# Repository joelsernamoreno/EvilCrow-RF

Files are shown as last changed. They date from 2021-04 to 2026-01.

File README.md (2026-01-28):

# EvilCrow-RF

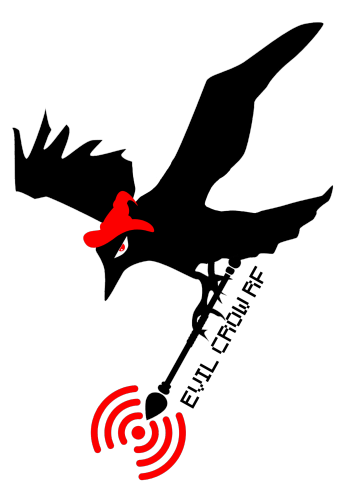
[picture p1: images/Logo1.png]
EvilCrow


**Idea, development and implementation:** Joel Serna (@JoelSernaMoreno).

**PCB design:** Ignacio Díaz Álvarez (@Nacon_96) and Forensic Security (@ForensicSec).

**Manufacturer and distributor:** April Brother (@aprbrother).

**Distributor from United Kingdom:** KSEC Worldwide (@KSEC_KC).

**Collaborators:** Little Satan, Ernesto Sánchez (@ernesto_xload), Federico Maggi (@phretor), Andrea Guglielmini (@Guglio95) and RFQuack (@rfquack).

The developers and collaborators of this project do not earn money with this. 
You can invite me for a coffee to further develop Low-Cost hacking devices. If you don't invite me for a coffee, nothing happens, I will continue developing devices.



**For sale with April Brother (shipping from China):** 

* [Aliexpress Shop](https://aliexpress.com/item/1005002476481892.html)

**For sale with KSEC Worldwide (shipping from United Kingdom):**

* Evil Crow RF: https://labs.ksec.co.uk/product/evil-crow-rf/

**Discord Group:** https://discord.gg/jECPUtdrnW

**Summary:**

1. Disclaimer
2. Introduction
3. Firmware
	* Installation
	* First steps with Evil Crow RF
	* Home
	* RX Config
	* Log Viewer
	* TX Config
	* Config
4. Advanced Firmware with RFQuack
	* Installation and first steps
	* RX Example
	* TX Example
	* Public Demo
5. Evil Crow RF Support

# Disclaimer

Evil Crow RF is a basic device for professionals and cybersecurity enthusiasts.

We are not responsible for the incorrect use of Evil Crow RF.

We recommend using this device for testing, learning and fun :D

**Be careful with this device and the transmission of signals. Make sure to follow the laws that apply to your country.**

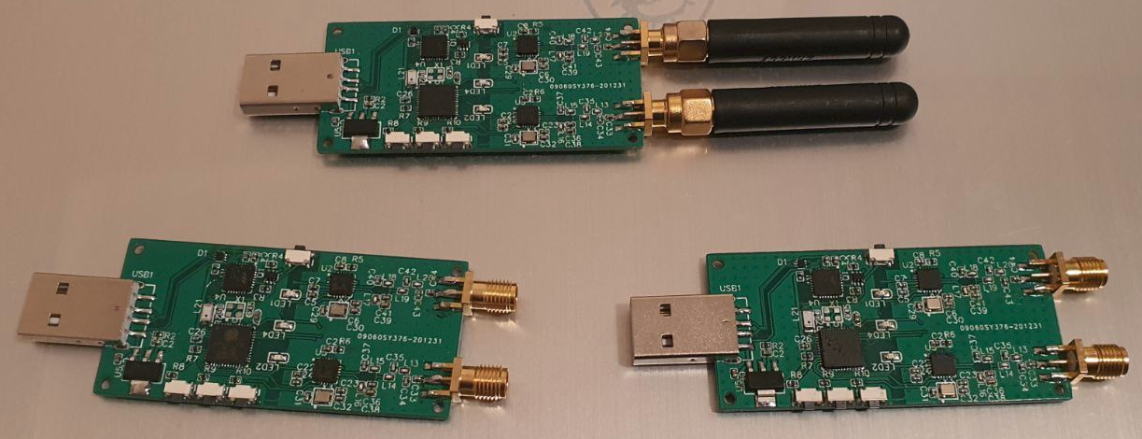
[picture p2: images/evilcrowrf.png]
EvilCrowRF


# Introduction

Evil Crow RF is a radiofrequency hacking device for pentest and Red Team operations, this device operates in the following radiofrequency bands:

* 300Mhz-348Mhz
* 387Mhz-464Mhz
* 779Mhz-928Mhz

Evil Crow RF has two CC1101 radiofrequency modules, these modules can be configured to transmit or receive on different frequencies at the same time.

Evil Crow RF allows the following attacks:

* Signal receiver
* Signal transmitter
* Replay attack
* Brute Force
* ...

**NOTE:** 

* All devices have been flashed with basic firmware EvilCrow-RF before shipping.
* Please do not ask me to implement new functions in this code. You can develop code for Evil Crow RF and send PR with your new code.

# Firmware

The basic firmware allows to receive and transmit signals. You can configure the two radio modules through a web panel via WiFi.

## Installation

1. Install esptool: sudo apt install esptool
2. Install pyserial: sudo pip install pyserial
3. Download and install the latest version of Arduino IDE (v2.3.6): https://www.arduino.cc/en/main/software
4. Download EvilCrow-RF repository: git clone https://github.com/joelsernamoreno/EvilCrow-RF.git
5. Download the ESPAsyncWebServer library in the Arduino library directory: git clone https://github.com/ESP32Async/ESPAsyncWebServer.git
6. Download the ElegantOTA library in the Arduino library directory: git clone https://github.com/ayushsharma82/ElegantOTA.git
7. Edit ElegantOTA/src/ElegantOTA.h and chage the following:

* #define ELEGANTOTA_USE_ASYNC_WEBSERVER 0 to #define ELEGANTOTA_USE_ASYNC_WEBSERVER 1

8. Download the AsyncTCP library in the Arduino library directory: git clone https://github.com/ESP32Async/AsyncTCP.git
9. Open Arduino IDE
10. Go to File - Preferences. Locate the field "Additional Board Manager URLs:" Add "https://espressif.github.io/arduino-esp32/package_esp32_index.json" without quotes. Click "Ok"
11. Select Tools - Board - Boards Manager. Search for "esp32". Install "esp32 by Espressif system version 3.3.2". Click "Close".
12. Open the EvilCrow-RF/firmware/firmware/firmware.ino sketch
13. Select Tools:
    * Board - "ESP32 Dev Module".
    * Flash Size - "4MB (32Mb)".
    * CPU Frequency - "80MHz (WiFi/BT)".
    * Flash Frequency - "40MHz"
    * Flash Mode - "DIO"
14. Upload the code to the Evil Crow RF device
15. Press reset button

## First steps with Evil Crow RF

1. Set up a Wi-Fi AP with your mobile phone:
	* **SSID:** Evil Crow RF
	* **Password:** 123456789ECRFv1
2. Connect your laptop to the same Wi-Fi network.
3. Open a browser and access the web panel: http://evilcrow-rf.local/

**Note:** If you cannot access the web panel, use the IP address assigned to Evil Crow RF or follow below steps **only if you are running Linux OS:**
 * check if avahi-deamon is installed and running on your PC. You can do this with executing "sudo systemctl status avahi-daemon" in terminal
 * If service is not running, install it using your package manager (apt, yum, dnf, Packman, rpm,...)
 * After successful installation, start avahi-daemon service with "sudo systemctl start avahi-daemon && sudo systemctl enable avahi-daemon"
 * In case evilcrow-rf.local is still not reachable, use http://"IP address", where "IP address" is IP assigned to Evil Crow RF.
 
## Home

The Home page shows interesting information about the device.

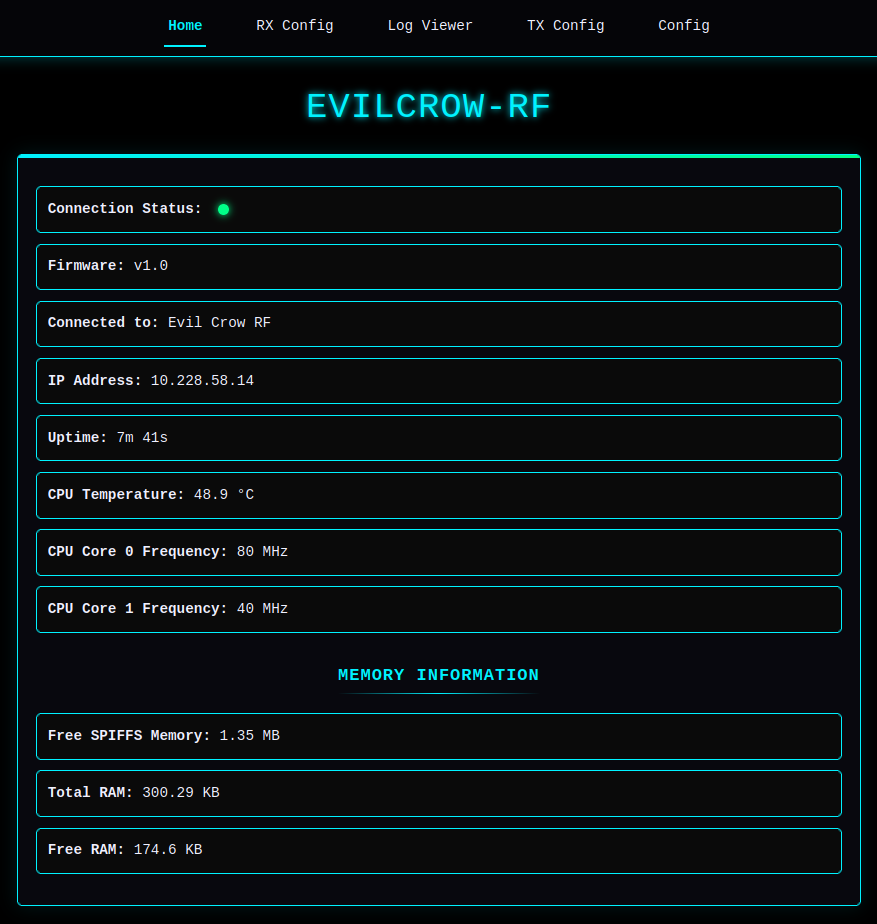
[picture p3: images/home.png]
Home


## RX Config

The RX Config page allows you to configure the CC101 modules for receiving signals. The received signals are displayed in the Log Viewer.

* Module: (1 for first CC1101 module, 2 for second CC1101 module)
* Modulation: (example ASK/OOK)
* Frequency: (example 433.92)
* Rx bandwidth: (example 200)
* Deviation: (example 0)
* Data rate: (example 5)

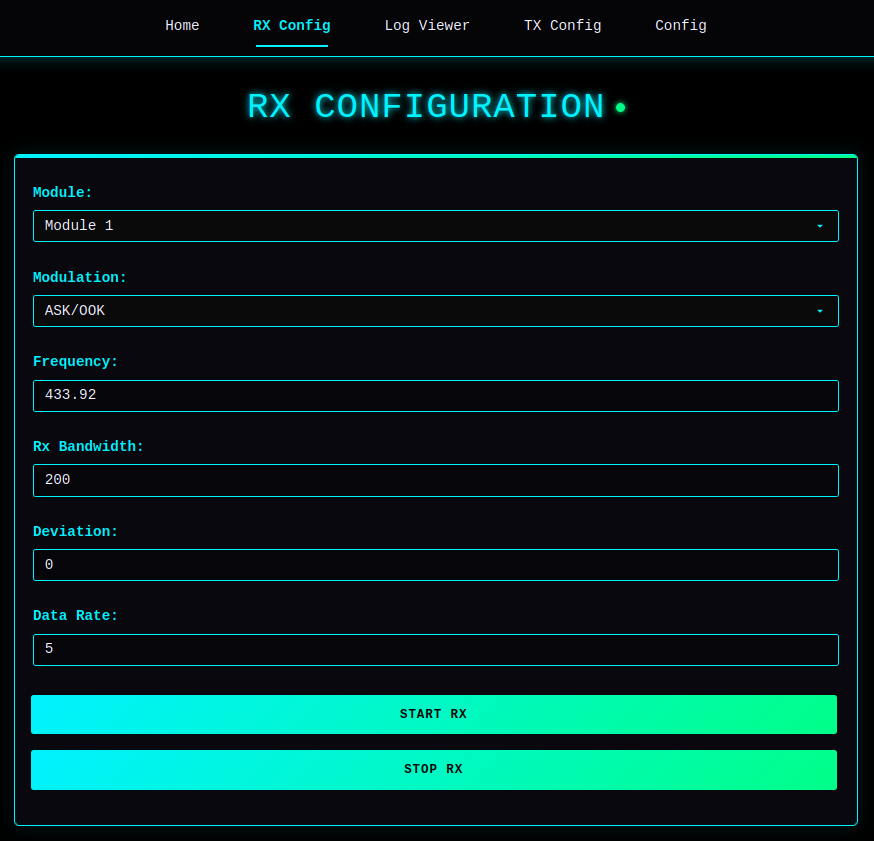
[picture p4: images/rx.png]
RX


## Log Viewer

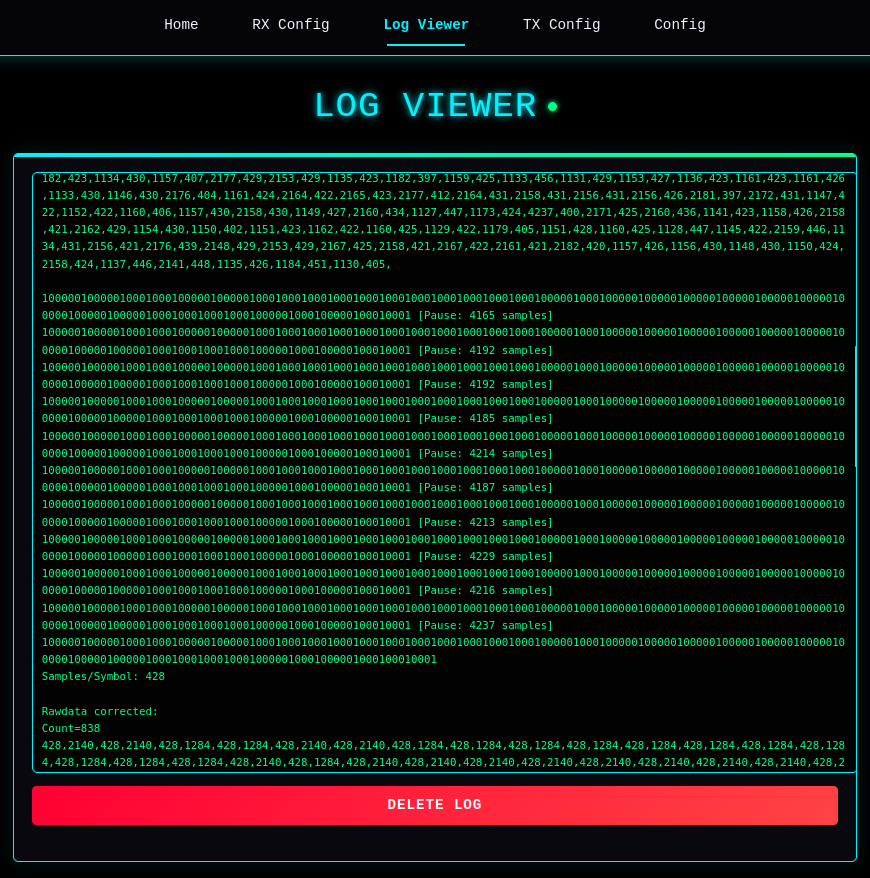
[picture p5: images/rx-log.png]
RXLog


## TX Config

The TX Config page allows you to transmit a raw data signal or enable/disable the jammer.

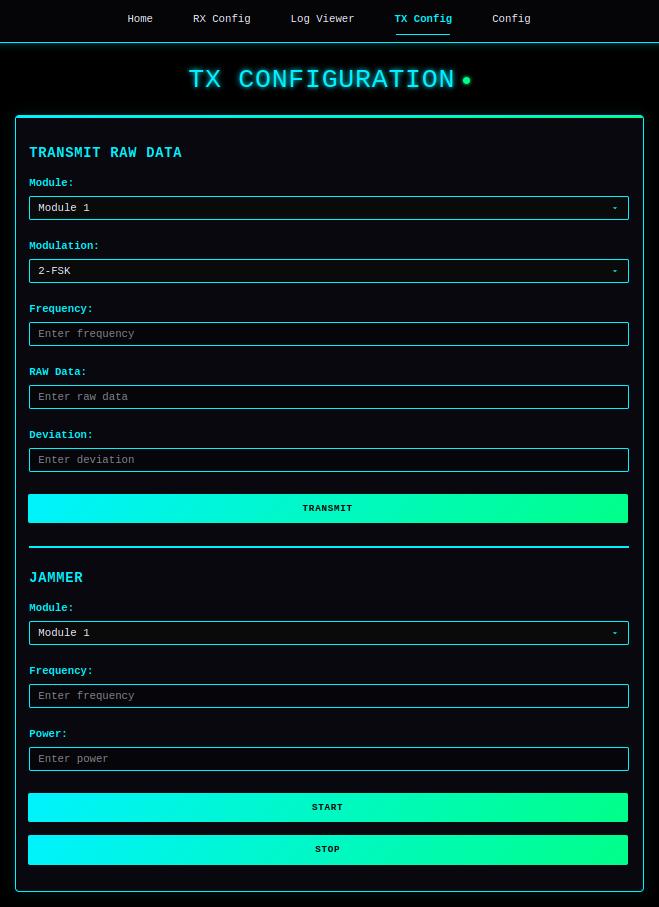
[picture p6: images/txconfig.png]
TXCONFIG


* **TX Raw Data:**

* Module: (1 for first CC1101 module, 2 for second CC1101 module)
* Modulation: (example ASK/OOK)
* Frequency: (example 433.92)
* RAW Data: (raw data or raw data corrected displayed in Log Viewer)
* Deviation: (example 0)

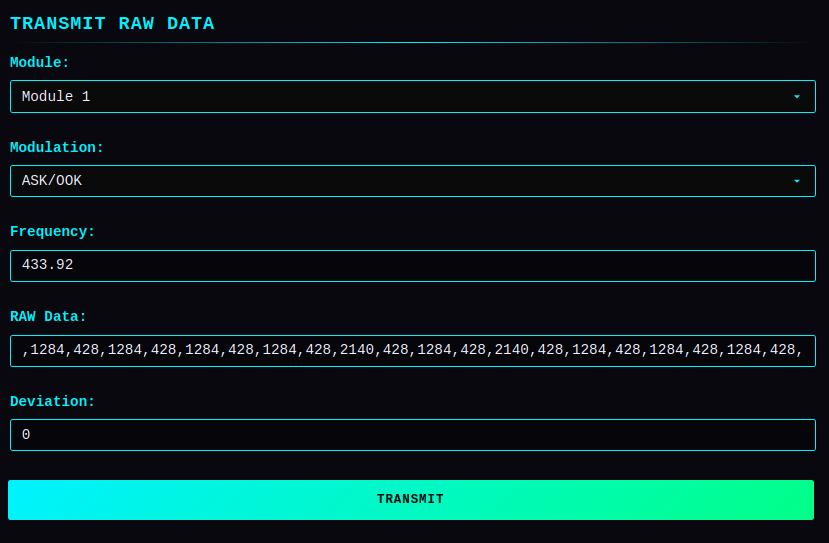
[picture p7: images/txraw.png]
TXRAW


* **Jammer:**

* Module: (1 for first CC1101 module, 2 for second CC1101 module)
* Frequency: (example: 433.92)
* Jammer Power: (example: 12)

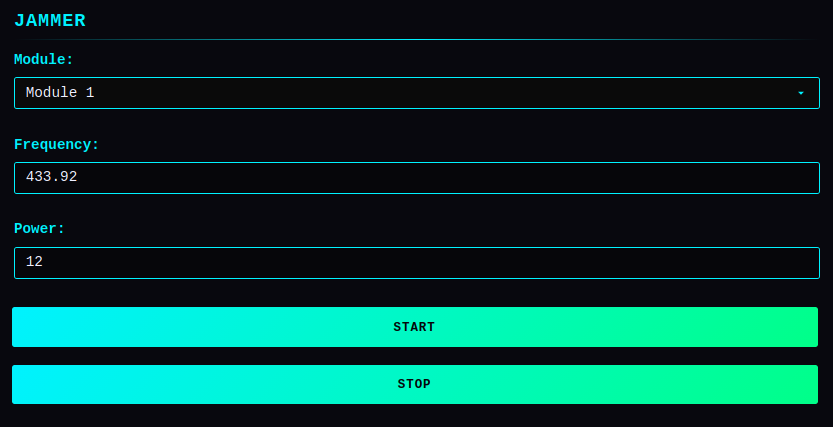
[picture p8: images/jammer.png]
JAMMER


## Config

The Config page allows you to change the Wi-Fi configuration.

**NOTE:** Evil Crow RF is configured in STATION MODE. You can change the ssid and password from the web panel.

The changes will be stored in the device, every time you restart Evil Crow RF the new Wi-Fi settings will be applied. If you want to return to the default settings, you can delete the stored Wi-Fi configuration from the web panel.

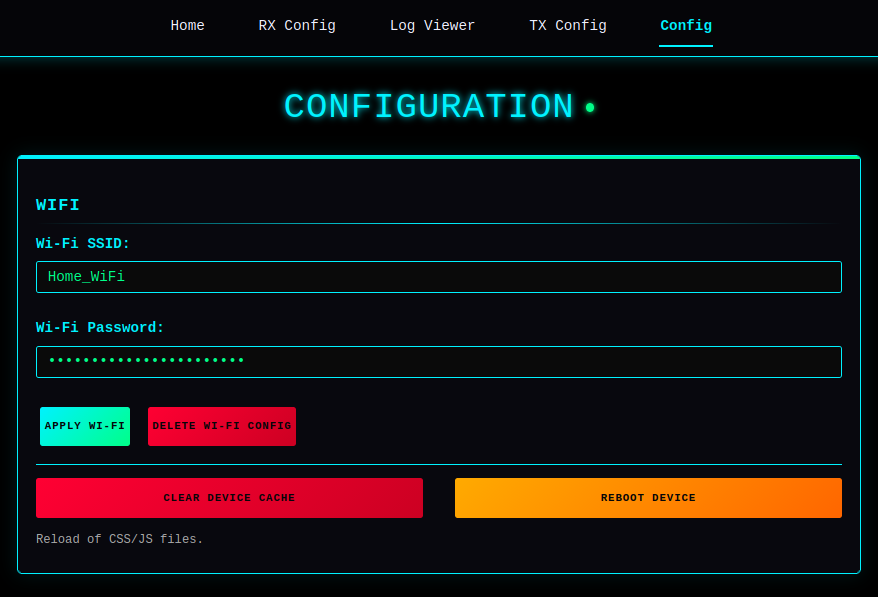
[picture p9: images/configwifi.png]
CONFIG


# Advanced Firmware with RFQuack

RFQuack is the only versatile RF-analysis tool that quacks!

It's a library firmware that allows you to sniff, manipulate, and transmit data over the air. Consider it as the hardware-agnostic and developer-friendly version of the great YardStick One, which is based on the CC1101 radio chip. Similarly to RFCat, RFQuack has a console-based, Python-scriptable client that allows you to set parameters, receive, transmit, and so on.

RFQuack is compatible with Evil Crow RF :D

## Installation and first steps

1. Download the RFQuack repository: git clone https://github.com/rfquack/RFQuack.git

2. Go to RFQuack directory: cd RFQuack

3. Edit build.env with this content:

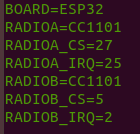
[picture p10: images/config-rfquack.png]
Content


4. Execute the following command: make docker-build-nc && make build

5. Connect Evil Crow RF to your computer and flash RFQuack with the following command: PORT=/dev/ttyUSB0 make flash

6. Disconnect and connect Evil Crow RF again

7. Download the RFQuack-cli repository: git clone https://github.com/rfquack/RFQuack-cli.git

8. Go to RFQuack-cli directory: cd RFQuack-cli

9. Execute the following command: make docker-build

10. Execute the following command: docker run --device /dev/ttyUSB0 --rm -it rfquack/cli:latest tty -P /dev/ttyUSB0

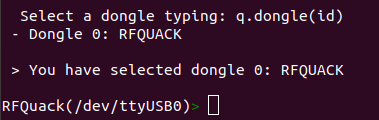
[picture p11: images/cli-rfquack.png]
Cli


## RX Example

In the RFQuack console run the following commands:

1. q.radioA.set_modem_config(modulation="OOK", carrierFreq=433.920, syncWords=b"", useCRC=False, bitRate=1.7*2, rxBandwidth=58)
2. q.radioA.set_packet_len(isFixedPacketLen=True, packetLen=100)
3. q.radioA.rx()

This is a simple example, read the documentation for information: https://github.com/rfquack/RFQuack

## TX Example

This example performs a replay attack with the signal received in the RX example.
In the RFQuack console run the following commands:

1. len(q.data)
2. q.radioA.tx()
3. q.radioA.send(data=q.data[0].data)

This is a simple example, read the documentation for information: https://github.com/rfquack/RFQuack

## Public Demo

* RX example: https://twitter.com/JoelSernaMoreno/status/1354854848299208706

# Evil Crow RF Support

* You can ask in the Discord group: https://discord.gg/jECPUtdrnW
* You can open issue or send me a message via twitter (@JoelSernaMoreno).

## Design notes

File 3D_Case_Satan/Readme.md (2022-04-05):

# Screwless housing for Evil Crow Rf v.1

"OldStyle"
The STL files do not contain support structures for 3D printing
You have to find out for yourself how it is best printed. 
I printed it with an SLA printer and had to print the housing parts upright for best printing results.

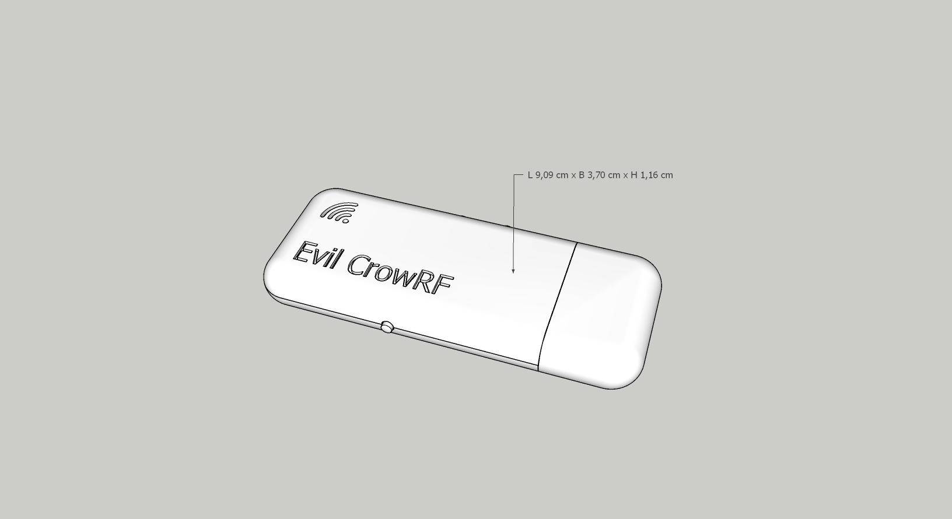
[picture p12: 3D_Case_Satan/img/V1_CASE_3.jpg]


"NewStyle"
Redesigned V1 case for better printability with the same size.(length including cap)

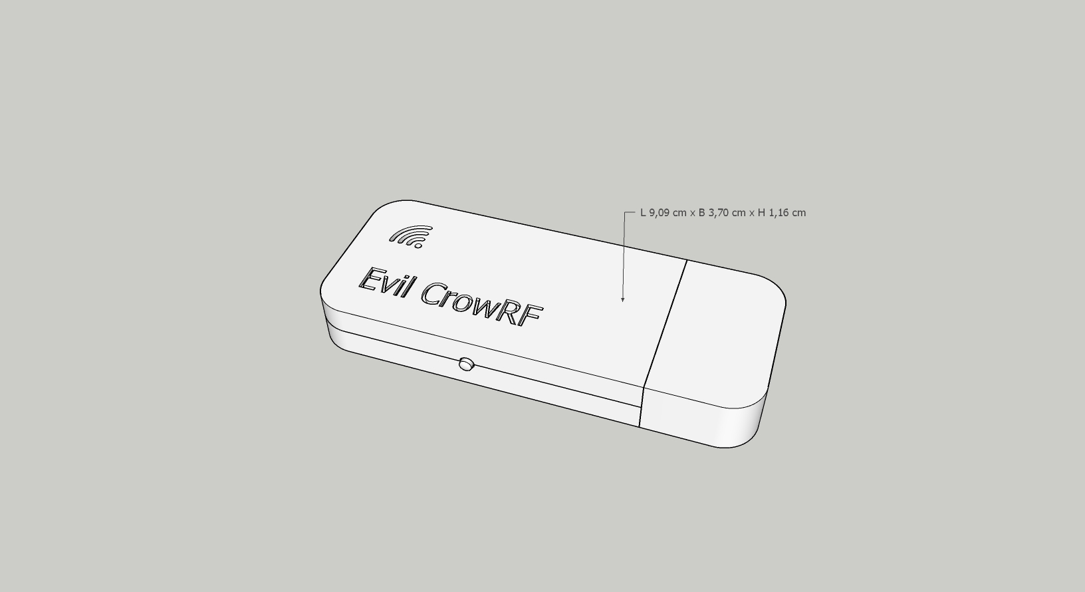
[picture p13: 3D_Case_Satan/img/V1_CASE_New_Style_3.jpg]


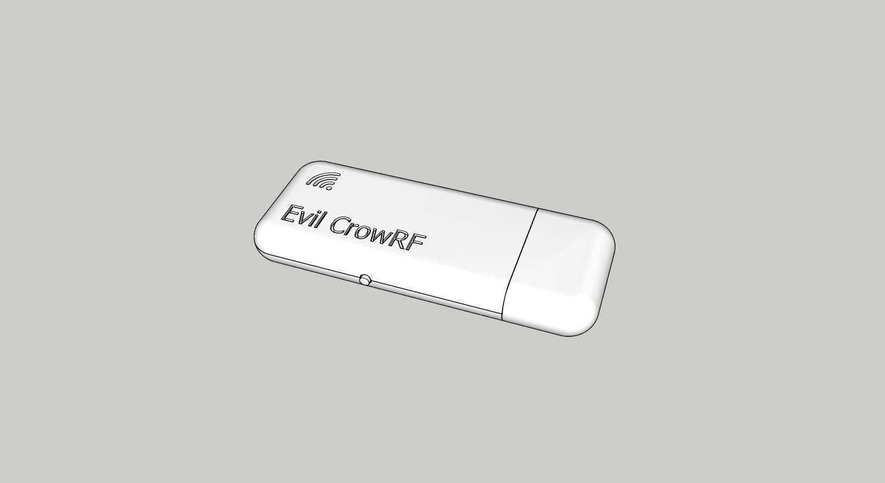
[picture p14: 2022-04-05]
3D_Case_Satan/img/V1_CASE_1.jpg

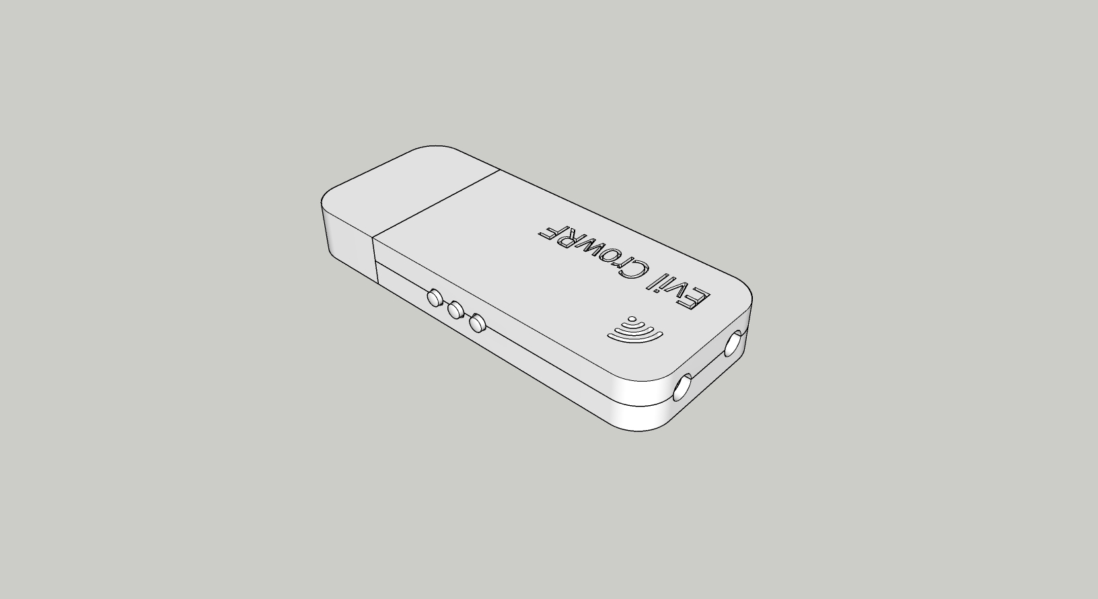
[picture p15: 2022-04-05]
3D_Case_Satan/img/V1_CASE_New_Style_2.jpg

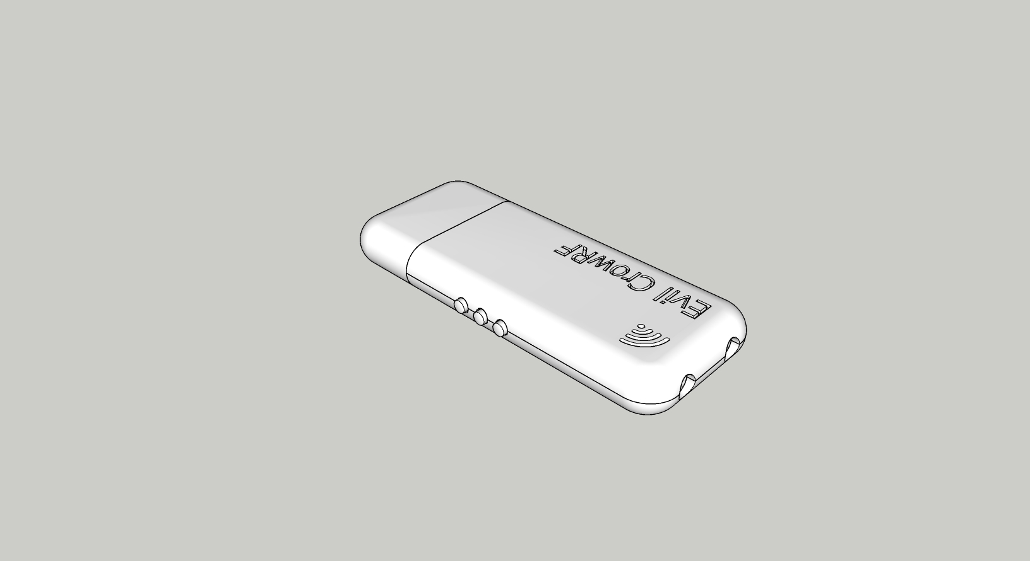
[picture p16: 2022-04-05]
3D_Case_Satan/img/V1_CASE_2.jpg

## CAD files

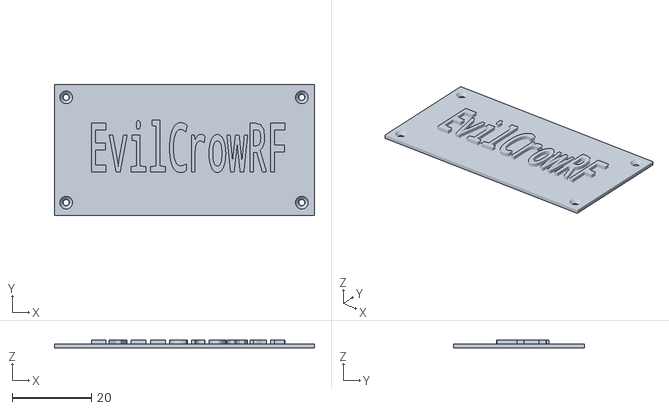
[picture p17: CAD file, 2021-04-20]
3D_Case/EvilCrowRF_Cover.stl
65.5 x 33.0 x 2.00

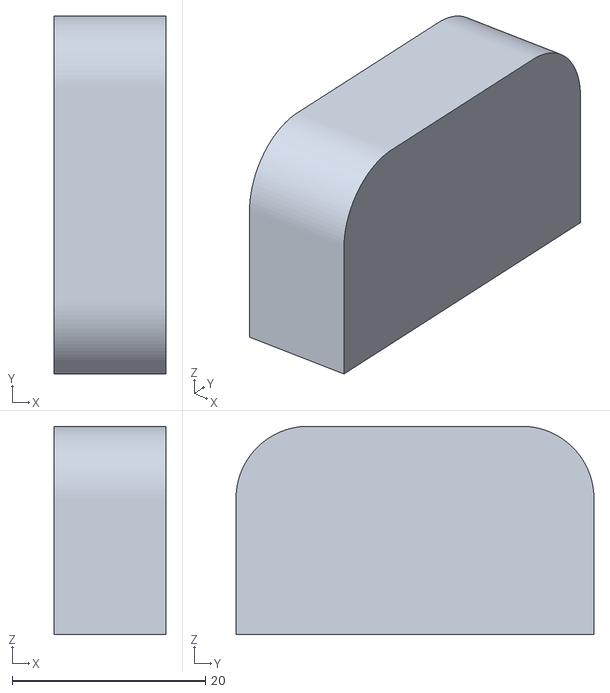
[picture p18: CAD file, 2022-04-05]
3D_Case_Satan/V1 CASE New Style STL/ECRF_NS_CAP.stl
11.6 x 37.1 x 21.6

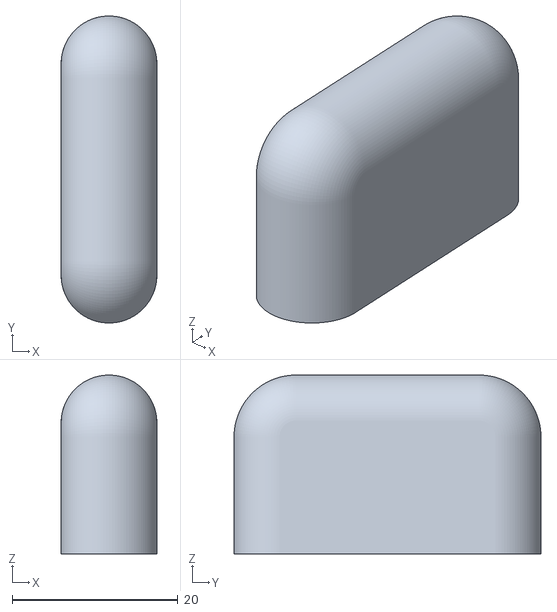
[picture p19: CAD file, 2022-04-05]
3D_Case_Satan/V1 CASE STL/ECRF_CAP.stl
11.6 x 37.1 x 21.6

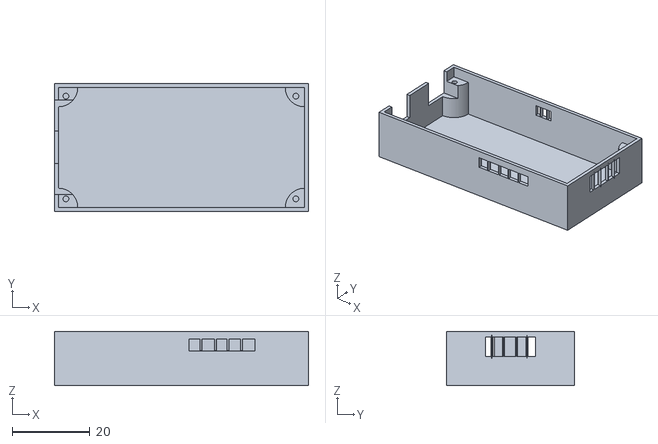
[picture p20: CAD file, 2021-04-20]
3D_Case/EvilCrowRF_Case.stl
65.5 x 33.0 x 14.0

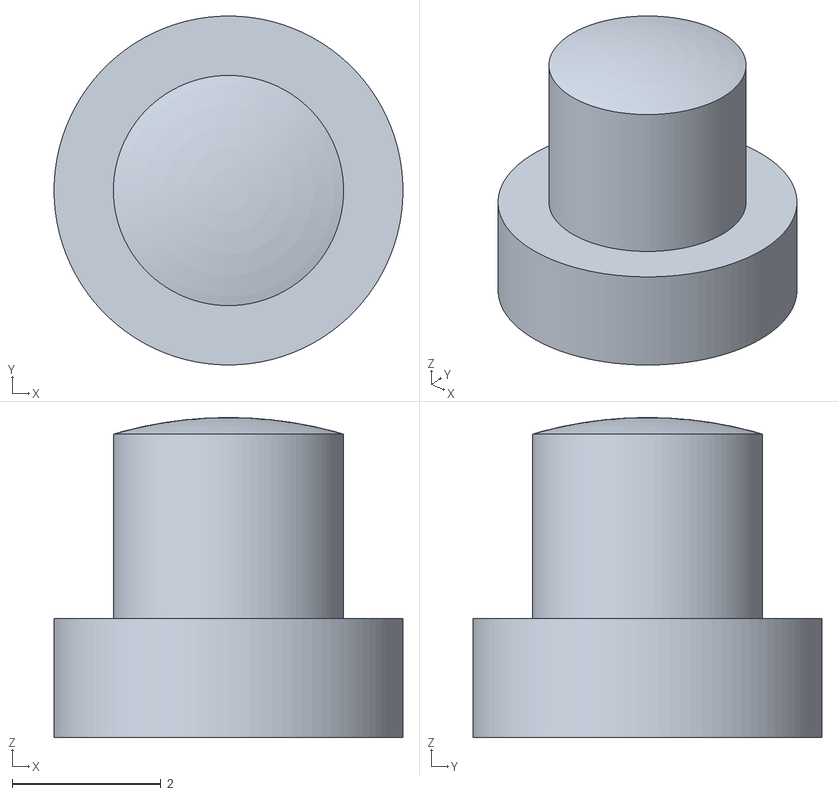
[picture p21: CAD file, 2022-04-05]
3D_Case_Satan/V1 CASE New Style STL/ECRF_1_2_3_BUTTON.stl
4.70 x 4.70 x 4.31

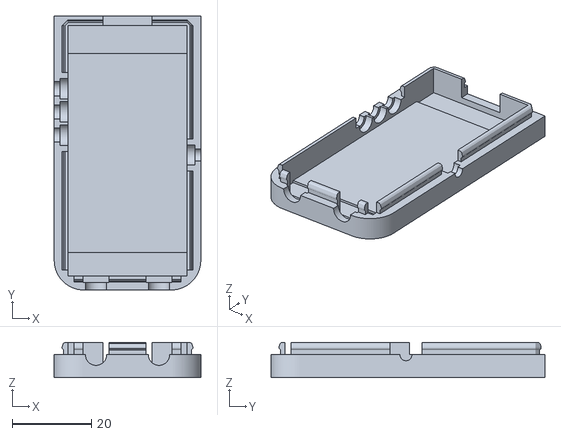
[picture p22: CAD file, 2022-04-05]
3D_Case_Satan/V1 CASE New Style STL/ECRF_NS_BOTTOM.stl
37.1 x 69.3 x 8.91

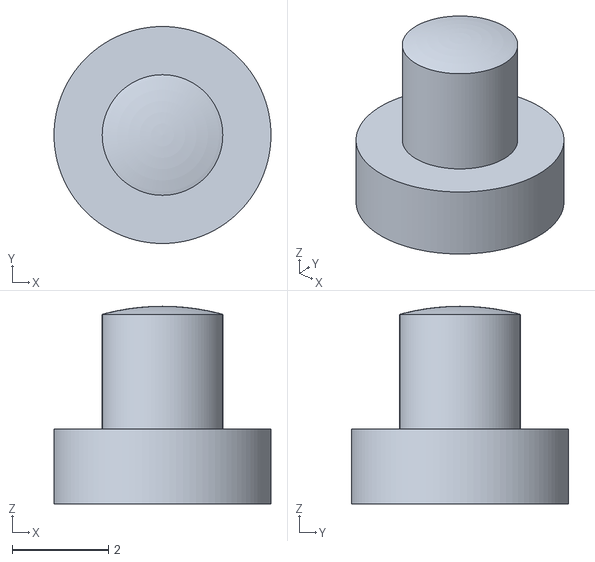
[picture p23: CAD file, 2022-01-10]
3D_Case_Satan/V1 CASE STL/ECRF_RST_BUTTON.stl
4.50 x 4.50 x 4.10

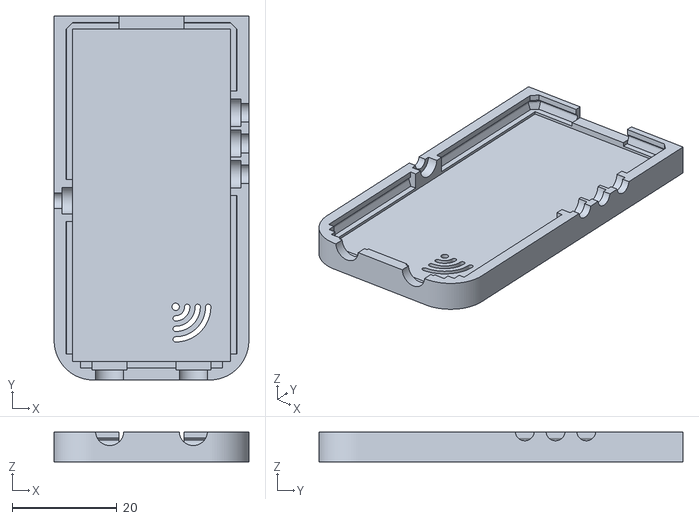
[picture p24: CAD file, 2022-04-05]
3D_Case_Satan/V1 CASE New Style STL/ECRF_NS_TOP.stl
37.1 x 69.3 x 5.66

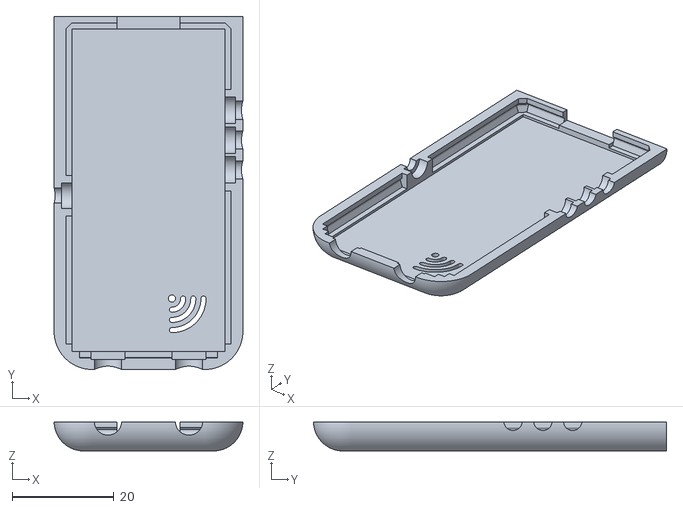
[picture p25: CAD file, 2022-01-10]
3D_Case_Satan/V1 CASE STL/ECRF_TOP.stl
37.1 x 69.3 x 5.66

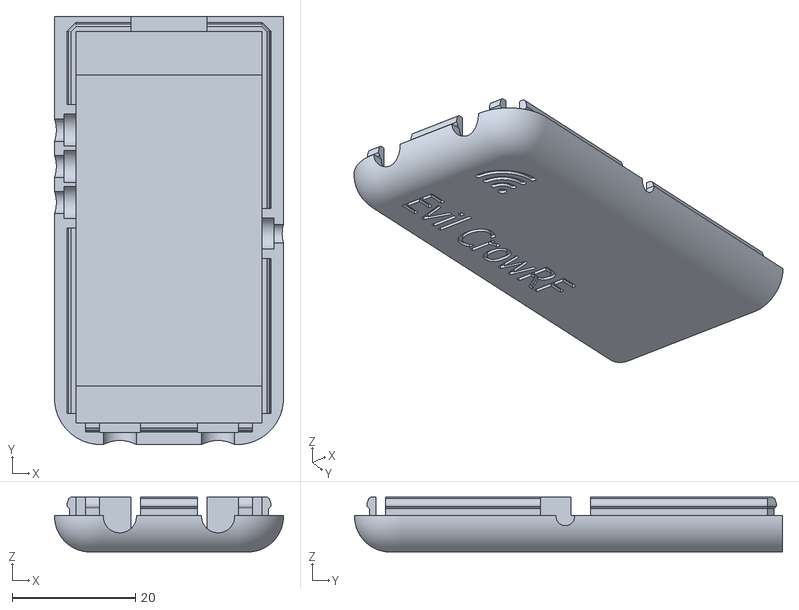
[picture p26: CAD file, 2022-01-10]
3D_Case_Satan/V1 CASE STL/ECRF_BOTTOM.stl
37.1 x 69.3 x 8.91

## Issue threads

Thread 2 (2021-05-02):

Schematics

leo-lb, 2021-05-02:
Hello!

Wonderful cheap device! As soon as I can get one I am looking forward to making it easier to use by creating better user interfaces and so on.

In the mean time, I would be curious to look at the schematics, where can I find them?

Thank you

joelsernamoreno, 2021-05-03:
Check your email :)

NicheSkill, 2023-10-02:
@joelsernamoreno Would you please email me the schematics as well ?
I have managed to get the device working till the home page load in browser. however I want to know  hardware schematics and connections for further modules.
basically this borad is not available in india so trying to build my own. I got cc1101 and NRF24L modules  but not sure how can i interface it.

Closed 2021-05-03.

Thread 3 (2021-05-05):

Steady RF Carrier output?

juergs, 2021-05-05:
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

Experiencing a steady RF Carrier, when pluged into USB?

Which functionality have LED 1..4?

Schematic?

joelsernamoreno, 2021-05-05:
Hi!

That's strange. Check my image:

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

Can you test this by connecting the device to an external battery? It is strange that Evil Crow RF generates that carrier.

About the leds... you can turn off/on them using these pins:

* led_1 = io12
* led_2 = io13
* led_3 = io15

About the schematics, tell me your email and I will send you

Thanks!

joelsernamoreno, 2021-05-05:
Can you check this with this code?

#include <ELECHOUSE_CC1101_SRC_DRV.h>
#include <RCSwitch.h>

RCSwitch mySwitch = RCSwitch();
RCSwitch CC1101_1 = RCSwitch();
RCSwitch CC1101_2 = RCSwitch();

//CC1101 Pins
int sck = 18;
int miso = 19;
int mosi = 23;
int csn1 = 5;
int csn2 = 27;
int gdo0_1 = 2;
int gdo2_1 = 4;
int gdo0_2 = 25;
int gdo2_2 = 26;

void setup() {
Serial.begin(38400);
ELECHOUSE_cc1101.setSpiPin(sck, miso, mosi, csn1);
ELECHOUSE_cc1101.setMHZ(433.92);
ELECHOUSE_cc1101.Init();
CC1101_1.enableTransmit(gdo0_1);
ELECHOUSE_cc1101.SetTx();
CC1101_1.send(1648498, 24);
delay(3000);
CC1101_1.send(1648498, 24);
delay(3000);
ELECHOUSE_cc1101.SetRx();
}

void loop() {
}

juergs, 2021-05-06:
Hi Joel,
thanks for that quick response. ;-)

I had overwritten the original flash-content and used your github-code, without modifications on the Elechouse-Lib.

I'll  check with your suggested testcode.

Thank you!
Juergen

juergs, 2021-05-06:
Hi Joel,

thank you very much for your work & time.

My email-address:          ***@***.*** ***@***.***>

I would appreciate to get a schematic, to check the error. 😉

Might be,  that I haven’t  used the second Radio, by setting it to receive mode?

We‘ll try to use this device for our german Homeautomation-System FHEM (https://fhem.de/)  as RF-gateway-device.

thank you + regards,

Juergen

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

joelsernamoreno, 2021-05-06:
Hello!

This has nothing to do with setting up the second radio. You can use one radio or use both radios. For both radios to work correctly you need to use the libraries included in the libraries folder. These libraries have been modified to make the device work correctly.

Try the example I have sent you. Possibly the carrier you see is a problem of the basic firmware. I have talked to some colleagues who have Evil Crow RF and there is one friend who has this problem too.

If the example I sent you works and you don't get the carrier, I will tell you how to fix this in the basic firmware

I look forward to your reply :)

Thanks!

juergs, 2021-05-06:
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

Other, but similar behavior: Carrier is there, but interrupted.

joelsernamoreno, 2021-05-06:
Can you try transmitting with the second module?

juergs, 2021-05-06:
Yes. Receiving with original FW was not possible ... with obvious "powerful" traffic nearby ... (;-(

juergs, 2021-05-06:
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

_ELECHOUSE_cc1101.setSpiPin(sck, miso, mosi, csn1);
ELECHOUSE_cc1101.setMHZ(433.92);
ELECHOUSE_cc1101.Init();

CC1101_1.enableTransmit(gdo0_1);
ELECHOUSE_cc1101.SetTx();

CC1101_1.send(1648498, 24);
delay(3000);
CC1101_1.send(1648498, 24);
delay(3000);
ELECHOUSE_cc1101.SetRx();

delay(3000);

ELECHOUSE_cc1101.setSpiPin(sck, miso, mosi, csn2);
ELECHOUSE_cc1101.setMHZ(433.92);
ELECHOUSE_cc1101.Init();

CC1101_2.enableTransmit(gdo0_2);
ELECHOUSE_cc1101.SetTx();

CC1101_2.send(1648498, 24);
delay(2000);
CC1101_2.send(1648498, 24);
delay(2000);
ELECHOUSE_cc1101.SetRx();_

joelsernamoreno, 2021-05-06:
Can't receive with the second module? For the second module to work you need to copy the libraries from the libraries folder (rcswitch and SmartRC) to your arduino libraries directory

About the schematics, check this: https://github.com/joelsernamoreno/EvilCrow-RF/tree/main/schematics

Can you try transmitting with the rfquack firmware and see if you get the carrier?

juergs, 2021-05-06:
Thank you, i will check, but will take some time ...

joelsernamoreno, 2021-05-06:
Okay, let me know if you have any problems with RFQuack

It is strange that you see that carrier, this is why I would like you to try the RFQuack firmware. I want to know if this is a firmware problem or a hardware problem

If it is a hardware problem you will have to talk to the manufacturer to send you a new one. Right now they are out of stock, but hopefully they will have stock soon

juergs, 2021-05-06:
https://e2e.ti.com/support/wireless-connectivity/sub-1-ghz/f/sub-1-ghz-forum/872424/cc1101-how-to-send-unmodulated-carrier-using-cc1101

compiling .pio\build\rf\libbe6\SmartRC-CC1101-Driver-Lib\ELECHOUSE_CC1101_SRC_DRV.cpp.o
libraries\SmartRC-CC1101-Driver-Lib\ELECHOUSE_CC1101_SRC_DRV.cpp: In member function 'void ELECHOUSE_CC1101::setPA(int)':
libraries\SmartRC-CC1101-Driver-Lib\ELECHOUSE_CC1101_SRC_DRV.cpp:403:16: warning: 'a' may be used uninitialized in this function [-Wmaybe-uninitialized]
 PA_TABLE[0] = a;
                ^

joelsernamoreno, 2021-05-06:
What do you want to tell me with this?

joelsernamoreno, 2021-05-06:
Anyway, can you tell me what SDR hardware you are using and what software? I will try to replicate your scenario

Example: hackrf with gqrx

juergs, 2021-05-06:
SDRSharp community package (Win10): [(https://airspy.com/download/)]
and USB-DVBT-Stick.

May be the antennas position is to near to transceiver ?
2m away there are some carrier traces visible.
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

joelsernamoreno, 2021-05-06:
That should not affect

I have spoken to LSatan, it seems to be a library problem. This is the response from LSatan:

"yes i know the narrow carrier signal. we should set set setSidle after sending. or SetRx. that should fix the problem."

Try the rfquack firmware and tell me if the carrier is still there

juergs, 2021-05-06:
Try the rfquack firmware and tell me if the carrier is still there.
I am searching all needed libs  ;-)

..\RFQuack\examples\RFQuack-esp32-CC1101-serial\src\main.cpp
..\RFQuack\src\radio

joelsernamoreno, 2021-05-06:
You can see the RFQuack section in my repository. In this section you have the steps to flash RFQuack in Evil Crow RF

https://github.com/joelsernamoreno/EvilCrow-RF/blob/main/README.md

juergs, 2021-05-06:
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

Seems to work now:

  ELECHOUSE_cc1101.setSpiPin(sck, miso, mosi, csn1);
  ELECHOUSE_cc1101.setMHZ(433.92);
//*************************************
  ELECHOUSE_cc1101.setPA(10);
//*************************************
  ELECHOUSE_cc1101.Init();

  CC1101_1.enableTransmit(gdo0_1);
  ELECHOUSE_cc1101.SetTx();

  CC1101_1.send(1648498, 24);
  Serial.println("TX_1)");
  delay(3000);

  CC1101_1.send(1648498, 24);
  Serial.println("TX_2)");
  delay(3000);

  CC1101_1.send(1648498, 24);
  Serial.println("TX_3)");
  delay(3000);

  CC1101_1.send(1648498, 24);
  Serial.println("TX_4)");
  delay(3000);

  ELECHOUSE_cc1101.SetRx();
  delay(3000);

//---------------------------------------------------
... and set PKTLEN = 0xFF

   //SpiWriteReg(CC1101_PKTLEN,   0x3D);
    SpiWriteReg(CC1101_PKTLEN,   0xFF);

joelsernamoreno, 2021-05-06:
Well, I'll modify this in the repository library

The SmartRC library in my repository is version v2.3. I am using this version because I had to modify the library to make both CC1101 modules work at the same time. I have also made this modification in the latest version of SmartRC, but in the latest version the two radio modules do not work at the same time even though I modified the library.

When I have free time I will modify the spi register with your change. I think setPA(10) has nothing to do with that carrier. SetPA is for increasing the transmit power. Anyway, if you want to use the basic firmware from my repository you can add setPA in the code.

LSatan and I are trying to make the latest version of SmartRC compatible with Evil Crow RF, but we haven't managed to make both CC1101 modules work at the same time yet. If you want you can help on this

Let me know if I can close this issue. Thank you very much!

juergs, 2021-05-06:
Thank you for your kind support!

RX is working, too     :-)

PartNum: 0
VERSION: 20
Module: 1
Frequency: 433.92
Bandwidth: 58.00
Received: 1648496 BIN: 110010010011101110000 / Codelen:24bitsProtocol: 5
Received: 1648496 BIN: 110010010011101110000 / Codelen:24bitsProtocol: 5
Received: 1648496 BIN: 110010010011101110000 / Codelen:24bitsProtocol: 5
Received: 1648498 BIN: 110010010011101110010 / Codelen:24bitsProtocol: 5

juergs, 2021-05-06:
You can close this issue.

>CC1101 modules work at the same time yet. If you want you can help on this
We have a 4 CC1101-module transceiver with Maplemini STM32F103 solution:
Take a look @:
[(https://github.com/Ralf9/SIGNALDuino/blob/dev-r412_cc1101/SIGNALDuino.ino) ]
for FHEM Homeautomation system.

joelsernamoreno, 2021-05-06:
Thanks!

Closed 2021-05-06.

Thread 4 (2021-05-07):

Add new features.

djecom1, 2021-05-07:
It's not realy a issues, but maybe someone can help me to add new features on the original firmware.
I found this repo (link below) and tried adding a "De Bruijn" part, but no luck so far.
I will try again, but maybe someone here could find an easier way than me!

[gusgorman/RFmoggy](https://github.com/gusgorman402/RFmoggy)

And many thanks Joel for this nice tool.

Jérôme.

joelsernamoreno, 2021-05-07:
Hello!

I can try to implement this with the basic firmware, but... have you tried this with Evil Crow RF and does it work?

This code uses ESP8266, possibly you have to change some things to make it work on ESP32 :)

joelsernamoreno, 2021-05-09:
I have adapted De Bruijn to work with Evil Crow RF. You can download this here:

https://mega.nz/file/x0ZT1QqL#RfCf--2aYiGoUCGTm1-YWoMBQLRcGm4GIEeIIM-_VO8

Try this and tell me if it works correctly

I have tested this but it seems strange to me. Bruijin transmits only once and gets stuck

djecom1, 2021-05-09:
At work today, I'll try it tomorrow.
Thank you!

joelsernamoreno, 2021-05-10:
Yes, you have to make some modifications to make it compile

I have adapted RFMoggly completely for Evil Crow RF. This afternoon I will upload the code to the repository. Be patient :)

joelsernamoreno, 2021-05-10:
The web application does not break when you run anything?

For example: When after transmitting with De bruijn you have to receive a message saying: signal sent. If you don't get this message it is because the code has broken

djecom1, 2021-05-10:
No problem :
"Signal is sent
 Return to main menu
 Return to XXX menu"
👍

Closed 2021-05-10.

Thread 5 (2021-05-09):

RollJam attack

sumanblack666, 2021-05-09:
Hi ..bought this at aliexpress and still waiting to receive it ...cant wait to play with it ...wondering why there's no samy's rolljam attack module available , i saw its available at https://github.com/rfquack/RFQuack/tree/8a9364766192ae660c95ee0392152190ab1d1176/src/modules/defaults ?

is this due to security reasons ?

joelsernamoreno, 2021-05-09:
Hi!

Are you talking about adding rolljam in the basic firmware?

sumanblack666, 2021-05-09:
Yes ..

joelsernamoreno, 2021-05-09:
I don't have that much free time to implement features that fast. We are currently working on a library for Evil Crow RF that does not depend on rc-switch. We're also working on properly adapting the latest version of SmartRC here. With the latest version of SmartRC there are some problems to use both radio modules at the same time, so the library in this repository is version 2.3.

The community can add new features to Evil Crow RF, you can PR if you have something new for the device :)

sumanblack666, 2021-05-09:
Understood .I'll try to implement once i receive the device .

joelsernamoreno, 2021-05-09:
Thank you!

I hope you understand this. The devices are developed in our free time and we don't make money with this, so we try to make them as cheap as possible

We can't offer a great feature support like hak5 or Great Scott Gadgets

LeonSmall512, 2023-08-01:
How much will u charge me to make a rolljam device.

Closed 2021-05-09.

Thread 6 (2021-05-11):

Receiver granularity

leo-lb, 2021-05-11:
Hello!

I am wondering how this device could be used as a standalone tool and will it be sufficient, in particular I am thinking of a spectrum analyzer, is it going to be precise enough or would you still need an RTL-SDR?

I am thinking of creating an Android app with easy autocompletion of RFQuack commands and some UI for specific tasks like signal analysis or spectrum analyzer.

Can you think of any limitations in the hardware that would prevent this from working?

Thank you

leo-lb, 2021-05-11:
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

I mean that you wouldnt need any other hardware to study RF protocols on the supported bands and retransmit/emulate/eavesdrop those protocols, of course given the available bandwidth etc. of the chips.

joelsernamoreno, 2021-05-11:
Depending on the signal you are analyzing. If the signal has some kind of encryption, you may need an sdr with other tools

leo-lb, 2021-05-11:
@joelsernamoreno I read you saying elsewhere that it was possible to access raw I/Q, is it possible to receive and transmit raw I/Q? Or are we limited to encode/decode present in hardware?

leo-lb, 2021-05-11:
@joelsernamoreno Yes this, thank you ! So both sides is supported, so why exactly would signal encryption be a problem to break here with the hardware? Thanks

joelsernamoreno, 2021-05-12:
If you receive the raw and transmit the raw no problem, but the interesting thing is to analyze the signal and see what it contains :)

leo-lb, 2021-05-12:
@joelsernamoreno Sure but I mean that in any case there wont be any limitation on what can be received or transmitted (besides bandwidth), correct?

Also what prevents C1101 to be plugged with GNU Radio considering it has raw TX/RX IQ?

joelsernamoreno, 2021-05-12:
I think that CC1101 modules cannot be connected to gnuradio. As I have told you before, this is not a SDR like rtl-sdr, hackrf, etc

joelsernamoreno, 2021-05-12:
Evil Crow RF is not an SDR. It is simply a "breakout board" for the TI CC1101 platform. It is not as flexible as an SDR. It has a limited set of input parameters that you can define and it will decode the data for you

leo-lb, 2021-05-13:
> Evil Crow RF is not an SDR. It is simply a "breakout board" for the TI CC1101 platform. It is not as flexible as an SDR. It has a limited set of input parameters that you can define and it will decode the data for you

If you can recv/send raw I/Q then it doesnt decode data for you?

leo-lb, 2021-05-13:
> I think that CC1101 modules cannot be connected to gnuradio. As I have told you before, this is not a SDR like rtl-sdr, hackrf, etc

I am thinking it may be about writing the driver?

joelsernamoreno, 2021-05-13:
You can receive raw data and decode, but this does not mean you can use the device with gnuradio, urh, gqrx, etc

There are a cc1101 plugin for urh, but I have never tested this:

https://github.com/SpaceTeddy/urh-cc1101_FEC_encode_decode_plugin

joelsernamoreno, 2021-05-13:
Read this: https://www.barrettcommunications.com.au/news/understanding-the-difference-between-sdr-and-hdr/

leo-lb, 2021-05-13:
Thank you! Reading!

joelsernamoreno, 2021-05-13:
I am closing this issue. If you have any doubt open another issue :)

Closed 2021-05-13.

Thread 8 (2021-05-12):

next production batch ?

timFaivre, 2021-05-12:
Hi,
sorry in advance to reach you here, but, ...

I see the hardware as unvailable on aliexpress : do you plan to lauch a second batch anytime soon ? I would be interested. Perhaps using croud supply if you need financing ?

joelsernamoreno, 2021-05-12:
Hello!

A few days ago we made the second batch with 29 devices. This sold out very fast

The manufacturer is making 100 devices to sell. I hope it doesn't take them too long to make this available for sale

I will write you here when Evil Crow RF is available :)

timFaivre, 2021-05-12:
Awesome ! I'm staying tuned.

MrTakfly, 2021-05-23:
It works every time in Windows 👍 Thank you for your help!

I'm currently implementing a multi-bank memory for recording and replaying signals. It's a bit clunky at the minute, but once I've polished it I will add a web interface and submit a PR! Again, great project! You're a wizard!

Pr0l1f1c, 2021-05-24:
Great tool, I'm excited myself to buy a few for my team! Thanks!

joelsernamoreno, 2021-05-24:
Hi
I think the stock will return this week

opless, 2021-05-24:
Hi, sorry for the comment spam, I'm also interested so commenting to receive updates.

gigawatts, 2021-06-01:
28 in stock right now

joelsernamoreno, 2021-06-01:
Stock!

Pr0l1f1c, 2021-06-01:
Thx for the heads up! I need a total of 28 for a class room but settled for 4 this time to allow others a chance to grab one. Thx again!

joelsernamoreno, 2021-06-01:
Hi @Pr0l1f1c

Hello

You can write me on twitter (@JoelSernaMoreno) and I will put you in contact with the manufacturer if you need a batch of several devices

Thanks!

joelsernamoreno, 2021-06-01:
I close this issue. If you ever need to know when new stock is available, please open a new issue

Thanks

Closed 2021-06-01.

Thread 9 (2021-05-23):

Uploading sketches to the device

MrTakfly, 2021-05-23:
Hi, I seem to have very hit and miss results when uploading firmware to the device.

I followed the installation instructions and it failed to connect multiple times, but then pressing the reset button when the device was mid connecting seems to work around 1 in 20 times. Is there a trick to this that I have missed?

Awesome project by the way! I will be submitting a PR with some funky features soon.

joelsernamoreno, 2021-05-23:
Hi!

What operating system are you using?

There are some people who have had the same problem in Debian, in Windows or Ubuntu there should not be this problem

MrTakfly, 2021-05-23:
Thanks for the speedy reply!

I'm running Debian so that may be my issue! I'll try again on my windows box and see what happens! Thanks dude!

joelsernamoreno, 2021-05-23:
When I have some free time I will try this in debian. I have tried this on ubuntu and windows and I have no problem uploading the code

Let me know if this works fine on your windows

MrTakfly, 2021-05-23:
It works every time in Windows 👍 Thank you for your help!

I'm currently implementing a multi-bank memory for recording and replaying signals. It's a bit clunky at the minute, but once I've polished it I will add a web interface and submit a PR! Again, great project! You're a wizard!

joelsernamoreno, 2021-05-23:
Oh, that sounds good. Thanks for helping with the device! :D

Closed 2021-05-23.

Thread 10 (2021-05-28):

Putting unit in programming mode

RChadwick7, 2021-05-28:
Is there a certain button combination that puts the Evil Crow in programming mode? Every time I try to flash RFQuack, it fails.

joelsernamoreno, 2021-05-28:
Are you using debian? It seems that debian does not correctly detect the device

In ubuntu it works perfectly

RChadwick7, 2021-05-29:
I'm using Ubuntu 16.04. This is the result of sudo PORT=/dev/ttyUSB0 make flash:

docker run --rm -it --device=/dev/ttyUSB0:/board --env-file build.env rfquack/rfquack
Installation ID is 19b4a875-dbab-4d58-a017-58220b7a2dde
Processing ESP32 (platform: espressif32; board: esp32doit-devkit-v1; framework: arduino)
Tool Manager: Installing platformio/framework-arduinoespressif32 @ ~3.10006.0
Downloading [####################################] 100%
Unpacking [####################################] 100%
Tool Manager: framework-arduinoespressif32 @ 3.10006.210326 has been installed!
Tool Manager: Installing platformio/tool-mkspiffs @ ~2.230.0
Tool Manager: tool-mkspiffs @ 2.230.0 has been installed!
Tool Manager: Installing platformio/tool-scons @ ~4.40100.2
Downloading [####################################] 100%
Tool Manager: tool-scons @ 4.40100.2 has been installed!
Verbose mode can be enabled via -v, --verbose option
CONFIGURATION: https://docs.platformio.org/page/boards/espressif32/esp32doit-devkit-v1.html
PLATFORM: Espressif 32 (3.2.0) > DOIT ESP32 DEVKIT V1
HARDWARE: ESP32 240MHz, 320KB RAM, 4MB Flash
DEBUG: Current (esp-prog) External (esp-prog, iot-bus-jtag, jlink, minimodule, olimex-arm-usb-ocd, olimex-arm-usb-ocd-h, olimex-arm-usb-tiny-h, olimex-jtag-tiny, tumpa)
PACKAGES:

framework-arduinoespressif32 3.10006.210326 (1.0.6)
tool-esptoolpy 1.30000.201119 (3.0.0)
tool-mkspiffs 2.230.0 (2.30)
toolchain-xtensa32 2.50200.97 (5.2.0)
LDF: Library Dependency Finder -> http://bit.ly/configure-pio-ldf
LDF Modes: Finder ~ chain, Compatibility ~ soft
Found 36 compatible libraries
Scanning dependencies...
Dependency Graph
|-- 0.0.1
| |-- 0.4.5+sha.29b8ee4
| |-- 0.6.2
| |-- 2.4.7
| |-- 1.6.0
| |-- 1.0.4
| |-- 4.3.0+sha.6e7e6be
| | |-- 1.0
| |-- 0.0.1+sha.925def4
| |-- 1.0
| |-- 1.0
| | |-- 1.0
Building in release mode
Compiling .pio/build/ESP32/src/main.cpp.o
In file included from /root/.platformio/lib/RFQuack/src/radio/RadioLibWrapper.h:17:0,
from /root/.platformio/lib/RFQuack/src/radio/RFQRFM69.h:5,
from /root/.platformio/lib/RFQuack/src/radio/drivers.h:4,
from src/main.cpp:25:
/root/.platformio/lib/RadioLib/src/RadioLib.h:50:4: warning: #warning "God mode active, I hope it was intentional. Buckle up, lads." [-Wcpp]
#warning "God mode active, I hope it was intentional. Buckle up, lads."
^
In file included from /root/.platformio/lib/RadioLib/src/TypeDef.h:4:0,
from /root/.platformio/lib/RadioLib/src/RadioLib.h:43,
from /root/.platformio/lib/RFQuack/src/radio/RadioLibWrapper.h:17,
from /root/.platformio/lib/RFQuack/src/radio/RFQRFM69.h:5,
from /root/.platformio/lib/RFQuack/src/radio/drivers.h:4,
from src/main.cpp:25:
/root/.platformio/lib/RadioLib/src/BuildOpt.h:124:57: note: #pragma message: RADIOLIB_PLATFORM: ESP32
#define RADIOLIB_PLATFORM "ESP32"
^
/root/.platformio/lib/RadioLib/src/RadioLib.h:55:41: note: in expansion of macro 'RADIOLIB_PLATFORM'
#pragma message "RADIOLIB_PLATFORM: " RADIOLIB_PLATFORM
^
In file included from /root/.platformio/lib/RFQuack/src/radio/drivers.h:4:0,
from src/main.cpp:25:
/root/.platformio/lib/RFQuack/src/radio/RFQRFM69.h: In member function 'virtual float RFQRF69::getRSSI(float&)':
/root/.platformio/lib/RFQuack/src/radio/RFQRFM69.h:140:5: warning: no return statement in function returning non-void [-Wreturn-type]
}
^
Generating partitions .pio/build/ESP32/partitions.bin
Compiling .pio/build/ESP32/lib0b2/Nanopb/pb_common.c.o
Compiling .pio/build/ESP32/lib0b2/Nanopb/pb_decode.c.o
Compiling .pio/build/ESP32/lib0b2/Nanopb/pb_encode.c.o
Compiling .pio/build/ESP32/lib0b2/Nanopb/spm-test/objc/c-header.c.o
Archiving .pio/build/ESP32/lib0b2/libNanopb.a
Archiving .pio/build/ESP32/libbca/libTinyGSM.a
Compiling .pio/build/ESP32/lib16c/MQTT/MQTTClient.cpp.o
Compiling .pio/build/ESP32/lib16c/MQTT/lwmqtt/client.c.o
Compiling .pio/build/ESP32/lib16c/MQTT/lwmqtt/helpers.c.o
Compiling .pio/build/ESP32/lib16c/MQTT/lwmqtt/packet.c.o
Compiling .pio/build/ESP32/lib16c/MQTT/lwmqtt/string.c.o
Archiving .pio/build/ESP32/lib16c/libMQTT.a
Compiling .pio/build/ESP32/lib2ab/Queue/cppQueue.cpp.o
Archiving .pio/build/ESP32/lib2ab/libQueue.a
Compiling .pio/build/ESP32/libed5/ArduinoLog/ArduinoLog.cpp.o
Archiving .pio/build/ESP32/libed5/libArduinoLog.a
Compiling .pio/build/ESP32/liba96/SPI/SPI.cpp.o
Archiving .pio/build/ESP32/liba96/libSPI.a
Compiling .pio/build/ESP32/liba25/RadioLib/ISerial.cpp.o
Compiling .pio/build/ESP32/liba25/RadioLib/Module.cpp.o
Compiling .pio/build/ESP32/liba25/RadioLib/modules/CC1101/CC1101.cpp.o
Compiling .pio/build/ESP32/liba25/RadioLib/modules/ESP8266/ESP8266.cpp.o
Compiling .pio/build/ESP32/liba25/RadioLib/modules/HC05/HC05.cpp.o
Compiling .pio/build/ESP32/liba25/RadioLib/modules/JDY08/JDY08.cpp.o
Compiling .pio/build/ESP32/liba25/RadioLib/modules/RF69/RF69.cpp.o
Compiling .pio/build/ESP32/liba25/RadioLib/modules/RFM9x/RFM95.cpp.o
Compiling .pio/build/ESP32/liba25/RadioLib/modules/RFM9x/RFM96.cpp.o
Compiling .pio/build/ESP32/liba25/RadioLib/modules/RFM9x/RFM97.cpp.o
Compiling .pio/build/ESP32/liba25/RadioLib/modules/SX1231/SX1231.cpp.o
Compiling .pio/build/ESP32/liba25/RadioLib/modules/SX126x/SX1261.cpp.o
Compiling .pio/build/ESP32/liba25/RadioLib/modules/SX126x/SX1262.cpp.o
Compiling .pio/build/ESP32/liba25/RadioLib/modules/SX126x/SX1268.cpp.o
Compiling .pio/build/ESP32/liba25/RadioLib/modules/SX126x/SX126x.cpp.o
Compiling .pio/build/ESP32/liba25/RadioLib/modules/SX127x/SX1272.cpp.o
Compiling .pio/build/ESP32/liba25/RadioLib/modules/SX127x/SX1273.cpp.o
Compiling .pio/build/ESP32/liba25/RadioLib/modules/SX127x/SX1276.cpp.o
Compiling .pio/build/ESP32/liba25/RadioLib/modules/SX127x/SX1277.cpp.o
Compiling .pio/build/ESP32/liba25/RadioLib/modules/SX127x/SX1278.cpp.o
Compiling .pio/build/ESP32/liba25/RadioLib/modules/SX127x/SX1279.cpp.o
Compiling .pio/build/ESP32/liba25/RadioLib/modules/SX127x/SX127x.cpp.o
Compiling .pio/build/ESP32/liba25/RadioLib/modules/SX128x/SX1280.cpp.o
Compiling .pio/build/ESP32/liba25/RadioLib/modules/SX128x/SX1281.cpp.o
Compiling .pio/build/ESP32/liba25/RadioLib/modules/SX128x/SX1282.cpp.o
Compiling .pio/build/ESP32/liba25/RadioLib/modules/SX128x/SX128x.cpp.o
Compiling .pio/build/ESP32/liba25/RadioLib/modules/Si443x/Si4430.cpp.o
Compiling .pio/build/ESP32/liba25/RadioLib/modules/Si443x/Si4431.cpp.o
Compiling .pio/build/ESP32/liba25/RadioLib/modules/Si443x/Si4432.cpp.o
Compiling .pio/build/ESP32/liba25/RadioLib/modules/Si443x/Si443x.cpp.o
Compiling .pio/build/ESP32/liba25/RadioLib/modules/XBee/XBee.cpp.o
Compiling .pio/build/ESP32/liba25/RadioLib/modules/nRF24/nRF24.cpp.o
Compiling .pio/build/ESP32/liba25/RadioLib/protocols/AFSK/AFSK.cpp.o
Compiling .pio/build/ESP32/liba25/RadioLib/protocols/AX25/AX25.cpp.o
Compiling .pio/build/ESP32/liba25/RadioLib/protocols/HTTP/HTTP.cpp.o
Compiling .pio/build/ESP32/liba25/RadioLib/protocols/Hellschreiber/Hellschreiber.cpp.o
Compiling .pio/build/ESP32/liba25/RadioLib/protocols/MQTT/MQTT.cpp.o
Compiling .pio/build/ESP32/liba25/RadioLib/protocols/Morse/Morse.cpp.o
Compiling .pio/build/ESP32/liba25/RadioLib/protocols/PhysicalLayer/PhysicalLayer.cpp.o
Compiling .pio/build/ESP32/liba25/RadioLib/protocols/RTTY/RTTY.cpp.o
Compiling .pio/build/ESP32/liba25/RadioLib/protocols/SSTV/SSTV.cpp.o
Archiving .pio/build/ESP32/liba25/libRadioLib.a
Compiling .pio/build/ESP32/liba7b/Base64/Base64.cpp.o
Archiving .pio/build/ESP32/liba7b/libBase64.a
Compiling .pio/build/ESP32/lib789/WiFi/ETH.cpp.o
Compiling .pio/build/ESP32/lib789/WiFi/WiFi.cpp.o
Compiling .pio/build/ESP32/lib789/WiFi/WiFiAP.cpp.o
Compiling .pio/build/ESP32/lib789/WiFi/WiFiClient.cpp.o
Compiling .pio/build/ESP32/lib789/WiFi/WiFiGeneric.cpp.o
Compiling .pio/build/ESP32/lib789/WiFi/WiFiMulti.cpp.o
Compiling .pio/build/ESP32/lib789/WiFi/WiFiSTA.cpp.o
Compiling .pio/build/ESP32/lib789/WiFi/WiFiScan.cpp.o
Compiling .pio/build/ESP32/lib789/WiFi/WiFiServer.cpp.o
Compiling .pio/build/ESP32/lib789/WiFi/WiFiUdp.cpp.o
Archiving .pio/build/ESP32/lib789/libWiFi.a
Compiling .pio/build/ESP32/lib919/WiFiClientSecure/WiFiClientSecure.cpp.o
Compiling .pio/build/ESP32/lib919/WiFiClientSecure/ssl_client.cpp.o
Archiving .pio/build/ESP32/lib919/libWiFiClientSecure.a
Compiling .pio/build/ESP32/lib14b/RFQuack/rfquack.pb.c.o
Compiling .pio/build/ESP32/lib14b/RFQuack/utils/regex/re.c.o
Archiving .pio/build/ESP32/lib14b/libRFQuack.a
Archiving .pio/build/ESP32/libFrameworkArduinoVariant.a
Compiling .pio/build/ESP32/FrameworkArduino/Esp.cpp.o
Compiling .pio/build/ESP32/FrameworkArduino/FunctionalInterrupt.cpp.o
Compiling .pio/build/ESP32/FrameworkArduino/HardwareSerial.cpp.o
Compiling .pio/build/ESP32/FrameworkArduino/IPAddress.cpp.o
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
RChadwick7, 2021-05-29:
I did see both LED's flash, so it looked like it was trying to do something.

joelsernamoreno, 2021-05-29:
That's strange, the firmwares from the Evil Crow RF repository can you upload them or do you also get error?

RChadwick7, 2021-05-29:
Here's the error I get when trying to upload Evil Crow firmware:

Sketch uses 791046 bytes (60%) of program storage space. Maximum is 1310720 bytes.
Global variables use 40352 bytes (12%) of dynamic memory, leaving 287328 bytes for local variables. Maximum is 327680 bytes.
An error occurred while uploading the sketch
esptool.py v3.0-dev
Serial port /dev/ttyUSB0
Traceback (most recent call last):
  File "/home/charles/.arduino15/packages/esp32/tools/esptool_py/3.0.0/esptool.py", line 3682, in <module>
    _main()
  File "/home/charles/.arduino15/packages/esp32/tools/esptool_py/3.0.0/esptool.py", line 3675, in _main
    main()
  File "/home/charles/.arduino15/packages/esp32/tools/esptool_py/3.0.0/esptool.py", line 3329, in main
    esp = chip_class(each_port, initial_baud, args.trace)
  File "/home/charles/.arduino15/packages/esp32/tools/esptool_py/3.0.0/esptool.py", line 263, in __init__
    self._port = serial.serial_for_url(port)
  File "/usr/local/lib/python2.7/dist-packages/serial/__init__.py", line 90, in serial_for_url
    instance.open()
  File "/usr/local/lib/python2.7/dist-packages/serial/serialposix.py", line 325, in open
    raise SerialException(msg.errno, "could not open port {}: {}".format(self._port, msg))
serial.serialutil.SerialException: [Errno 13] could not open port /dev/ttyUSB0: [Errno 13] Permission denied: '/dev/ttyUSB0'

RChadwick7, 2021-05-29:
Also, I don't know if it makes a difference, but I'm running Ubuntu 16.04 in a VM under Windows.

joelsernamoreno, 2021-05-29:
On virtual machines it does not work correctly, try to do it on a physical machine.

Anyway, I'm seeing that the error you are getting is that you don't have permissions on /dev/ttyUSB0

If this still does not work you can contact me on twitter (@JoelSernaMoreno) and I can connect remotely to your computer to fix this

RChadwick7, 2021-05-29:
Unfortunately, I don't have a Linux machine. Do you know if RFQuack could be flashed in Windows?

joelsernamoreno, 2021-05-30:
We tried to flash rfquack on windows but we didn't succeed

You can try it or ask in the rfquack repository

joelsernamoreno, 2021-05-30:
First try flashing the Evil Crow RF firmware with your physical windows. With this we can know that your device does not have any factory problem

RChadwick7, 2021-05-30:
I successfully flashed using Arduino under Windows. Looks like you were right, the issue is with the VM. Too bad RFQuack doesn't have an .INO sketch.

joelsernamoreno, 2021-05-30:
You can try to flash rfquack with Windows. If this doesn't work you will have to open issue in the rfquack repository or flash this with linux

joelsernamoreno, 2021-06-01:
I close this issue. If you have any problems, open another issue or contact me directly on twitter

Thanks

Closed 2021-06-01.

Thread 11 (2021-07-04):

LED programming

Azanot, 2021-07-04:
Hi Joel, congratulations for your work.
I bought 2 devices.
Why not use the 3 LEDs to have a better understanding of the operation of the device?!
Also use a led to indicate signal reception as a "tester"
Example:
LED 1 = Power on signal (As now) :)
LED 2 = On when receiving signal / Flashing if signal in log memory.
LED 3 = On steady or flashing when transmitting a signal.
Thanks for your attention.

joelsernamoreno, 2021-07-04:
Hi!

Yes, you can turn the LEDs on and off with a task. This has not been implemented because each person has to decide when to turn on and off the leds.

The pins are as follows:

led_1 io12
led_2 io13
led_3 io15

Thanks!

Azanot, 2021-07-04:
Thank you for your reply. Unfortunately I don't have the skills to program. Your devices fascinate expert and non-expert users.
For this reason i thought you would program this and other function as an example "De Bruijn attack", "ROLLJAM" ecc..
Expert user will change the code, non-expert user (like me) will not have the function. Thanks for your attention. My is only suggestion that can increase your sales ;)

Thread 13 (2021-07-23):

Cannot connect to device using RFQuack

Pr0l1f1c, 2021-07-23:
I've been having the same issue since I received my EvilCrowRF-RF devices. I keep getting "Wrong dongle id" no matter what I insert as q.dongle(id).

When attempting to adjust any settings using "q.radioA" or "q.radioB" I receive... "'RFQuack' object has no attribute 'radioA'.

As of now, outside of using your available sketches, it appears that I'm officially stuck at using RFQuack in conjunction with EvilCrowRF-RF.

I teach a class on various radio topics and I wish to purchase more devices in order to use RFQuack in a much more compact and simpler form instead of having my class attendees build they're own RFQuack devices (the headaches that come along with this are absurd lol).

joelsernamoreno, 2021-07-23:
Hi!

I think this is not an Evil Crow RF issue, it seems that the RFQuack firmware is currently not working.

Check my issue:

https://github.com/rfquack/RFQuack-cli/issues/7

https://github.com/rfquack/RFQuack/issues/9

Maybe it is possible to use an older version of rfquack, I will try this when I have free time.

Thanks!

joelsernamoreno, 2021-07-25:
Hi!

Try this:

[rfquack-old.pdf](https://github.com/joelsernamoreno/EvilCrow-RF/files/6873232/rfquack-old.pdf)

Closed 2021-07-30.

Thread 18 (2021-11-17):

Problems with TX

skaken, 2021-11-17:
I’ve got my hands on a second batch unit and I’m playing around with it but I can’t seem to get it transmitting. I flashed it with the newer RAWv2.2-NewerInterface and everything seems to work on the RX side of things. My test object is a wireless doorbell at 433.92mhz, which I believe uses a simple ASK/OOK but I also tried FSK. Sniffing seems to work and I got everything in the logs, but transmitting either raw data or binary data doesn’t work and I get no errors. Do you have any idea if I’m doing something stupidly wrong or have missed something very obvious? (Should any of the LEDs indicate something during RX/TX?)  I’m a little unsure if I’m using the RxBW, Deviation and Data rate correct, and I would really appreciate some insight into this.
Thank you very much for all your work, Joel!

joelsernamoreno, 2021-11-17:
Hello!

Can you check with an SDR that the device is transmitting?

Can you join the discord group to be able to analyze the signal?

Thanks

skaken, 2021-11-17:
Thanks for your quick response, Joel! I haven’t got as far as getting myself an SDR yet(hard to pick one nowadays), but I might have to get myself a cheap RTL-SDR for the minor things.

I’ll do a bit more testing on some other RF equipment if you don’t have something obvious I should check, and join the discord group!

joelsernamoreno, 2021-11-17:
If this is ASK this should work:

Freq: 433.92
Mod: ASK/OOK
RxBw: between 58 and 100
Datarate: 5

Then go to log and copy the raw data, if this does not work you can try with the corrected raw data

Go to RAW TX and transmit the data by adding a comma at the end

You can join the discord channel to help you better if this doesn't work

I close this issue

Thanks

Closed 2021-11-17.

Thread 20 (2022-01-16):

bad USB ?

oshri-almog, 2022-01-16:
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

Are you familiar with this issue?
What are my options To debug this issue and solve it myself?
Most likely I need to solder one of the wires to the usb?
p.s.
I can login to the web UI.

tompusey, 2022-01-16:
I had the same problem initially, have a look at issue 16 for the fix. [https://github.com/joelsernamoreno/EvilCrow-RF/issues/16]

joelsernamoreno, 2022-01-16:
Exactly, check what @tompusey says

oshri-almog, 2022-01-23:
Thanks a lot it's work

Closed 2022-01-23.

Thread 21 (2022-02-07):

Adding oled to ecrf?

realone414, 2022-02-07:
How hard would it be to add an oled screed to the board using an arduino oled and header pins

joelsernamoreno, 2022-02-07:
There are currently no visible pads to solder this. You will need to solder this directly to the pins of the ESP

realone414, 2022-02-08:
Is there a license I can buy from you to purchase the complete schematics,
bom and gerber files to make only 1? I would like to build 1 and try to add
a couple functions as well as redesign it a little and make extremely good
quality enclosures with my creality cr-30 3d printer. I would be more than
happy to share all of my work back with you and send you anything you need.
Please help me, I have been completely obsessed with this project and can't
sleep because of all the ideas I have.  I can't find a single one to buy
anywhere and I'm so impatient.  Thank you for the reply, I how to hear from
you soon.

On Mon, Feb 7, 2022, 6:05 AM Joel Serna Moreno ***@***.***>
wrote:

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

Closed 2022-03-03.

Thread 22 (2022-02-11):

Can’t find device on arduino IDE

merdeux50, 2022-02-11:
Hello,

I’ve finally got the evil crow rf from Aliexp, but I can’t connect to it via arduino ide, I use OS X. I’ve tried via virtualbox running Windows 7 and 10, and no luck.

Even using it as is, I manage to connect to the device with my phone but it doesn’t seem to log any data.

Please help.

joelsernamoreno, 2022-02-11:
Hi!

I don't have a Mac and virtual machines don't work well here

How are you configuring Evil Crow RF and what remote control are you using?

Join the discord channel, there you can ask questions and we will try to fix the problem

Closed 2022-03-03.

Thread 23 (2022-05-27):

Satan v1 new style case tolerances

gigawatts, 2022-05-27:
Printed out the case in PLA on my Ender3 Pro, and it's just a wee bit too tight.

I can shove the PCB in, but it's so tight the buttons don't fit without depressing the 3 switches.

Have you heard any other reports of this? I might try re-printing at ~100.5% in all 3 dimensions.

gigawatts, 2022-06-06:
Printed at 100.7% and it fit well enough

joelsernamoreno, 2022-06-08:
@LSatan

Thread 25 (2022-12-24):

Where are the instructions?

WULFFJ, 2022-12-24:
I bought three of these to do some testing on.  I am newer to RF, but not programming.  Everything installed fine.  However, the lack of instructions is horrible.

What is the power jammer parameter for or what should be assigned?

Do all the other functions of this device call for another sketch?  This device gets advertised as an all in one???

Where are any guides on anything 2.4ghz related for the v2?

How does this integrate with URH?  You have a video of it, but its selecting another device.  Is it another device that is listening to the Evil Crow?

Overall, these directions don't give a good direction of where to start and is rather annoying.

Commander-Crash, 2022-12-26:
Agree. The web interface can use some explaining. I wish it was compatible with RFCAT but it seems like it is not a good alt for the YS1

Crsarmv7l, 2023-04-09:
> Agree. The web interface can use some explaining. I wish it was compatible with RFCAT but it seems like it is not a good alt for the YS1

I have been looking for something like rfcat but with less plug/unplug and more stable. Thought it might be rfquack but that has its own issues.

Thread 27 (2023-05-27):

PCB design files

gigawatts, 2023-05-27:
Can you publish the PCB design files, or at least an image of where all the traces are, for the EvilCrow RF v1 hardware?

I'm pretty sure I managed to fry the flash in the ESP32 on my board with a bad FFat partitioning scheme (all I get now is `flash read err` errors from esptool). So I would like to either try and obtain another ESP32-PICO-D4 chip and use a hot air rework gun to swap it out, OR chop up the current board and make use of the CC1101 radios with other projects (like an external radio for my Flipper Zero). Having a good reference of where all the traces are would help me out, whichever path I take.

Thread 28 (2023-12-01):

evil crow rf v2 error when flashing the firmware (download mode needed)

igor1019, 2023-12-01:
How can I put my evil crow rf v2 in download mode to flash firmware?
I have been receiving this error below in ESPHome-flasher when installing the firmware:

Using 'COM10' as serial port.
Connecting......................................
Unexpected error: ESP is not in flash boot mode. If your board has a flashing pin, try again while keeping it pressed.

Thank you so much!

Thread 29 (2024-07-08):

Getting error when trying to test compile in arduino IDE

kavemang, 2024-07-08:
`
In file included from /home/kaveman/.arduino15/packages/esp32/hardware/esp32/3.0.2/libraries/WebServer/src/HTTP_Method.h:4,
                 from /home/kaveman/.arduino15/packages/esp32/hardware/esp32/3.0.2/libraries/WebServer/src/WebServer.h:30,
                 from /home/kaveman/Arduino/libraries/ElegantOTA/src/ElegantOTA.h:73,
                 from /home/kaveman/Arduino/libraries/EvilCrow-RF/EvilCrowRF-RAWv2/RAWv3.0-NewInterface/RAWv3.0-NewInterface.ino:6:
/home/kaveman/.arduino15/packages/esp32/tools/esp32-arduino-libs/idf-release_v5.1-bd2b9390ef/esp32/include/http_parser/http_parser.h:95:6: error: 'HTTP_DELETE' conflicts with a previous declaration
   95 |   XX(0,  DELETE,      DELETE)       \
      |      ^
/home/kaveman/.arduino15/packages/esp32/tools/esp32-arduino-libs/idf-release_v5.1-bd2b9390ef/esp32/include/http_parser/http_parser.h:138:45: note: in definition of macro 'XX'
  138 | #define XX(num, name, string) HTTP_##name = num,
      |                                             ^~~
/home/kaveman/.arduino15/packages/esp32/tools/esp32-arduino-libs/idf-release_v5.1-bd2b9390ef/esp32/include/http_parser/http_parser.h:139:3: note: in expansion of macro 'HTTP_METHOD_MAP'
  139 |   HTTP_METHOD_MAP(XX)
      |   ^~~~~~~~~~~~~~~
In file included from /home/kaveman/Arduino/libraries/EvilCrow-RF/EvilCrowRF-RAWv2/RAWv3.0-NewInterface/RAWv3.0-NewInterface.ino:5:
/home/kaveman/Arduino/libraries/ESPAsyncWebServer/src/ESPAsyncWebServer.h:64:3: note: previous declaration 'WebRequestMethod HTTP_DELETE'
   64 |   HTTP_DELETE  = 0b00000100,
      |   ^~~~~~~~~~~
/home/kaveman/.arduino15/packages/esp32/tools/esp32-arduino-libs/idf-release_v5.1-bd2b9390ef/esp32/include/http_parser/http_parser.h:96:6: error: 'HTTP_GET' conflicts with a previous declaration
   96 |   XX(1,  GET,         GET)          \
      |      ^
/home/kaveman/.arduino15/packages/esp32/tools/esp32-arduino-libs/idf-release_v5.1-bd2b9390ef/esp32/include/http_parser/http_parser.h:138:45: note: in definition of macro 'XX'
  138 | #define XX(num, name, string) HTTP_##name = num,
      |                                             ^~~
/home/kaveman/.arduino15/packages/esp32/tools/esp32-arduino-libs/idf-release_v5.1-bd2b9390ef/esp32/include/http_parser/http_parser.h:139:3: note: in expansion of macro 'HTTP_METHOD_MAP'
  139 |   HTTP_METHOD_MAP(XX)
      |   ^~~~~~~~~~~~~~~
/home/kaveman/Arduino/libraries/ESPAsyncWebServer/src/ESPAsyncWebServer.h:62:3: note: previous declaration 'WebRequestMethod HTTP_GET'
   62 |   HTTP_GET     = 0b00000001,
      |   ^~~~~~~~
/home/kaveman/.arduino15/packages/esp32/tools/esp32-arduino-libs/idf-release_v5.1-bd2b9390ef/esp32/include/http_parser/http_parser.h:97:6: error: 'HTTP_HEAD' conflicts with a previous declaration
   97 |   XX(2,  HEAD,        HEAD)         \
      |      ^
/home/kaveman/.arduino15/packages/esp32/tools/esp32-arduino-libs/idf-release_v5.1-bd2b9390ef/esp32/include/http_parser/http_parser.h:138:45: note: in definition of macro 'XX'
  138 | #define XX(num, name, string) HTTP_##name = num,
      |                                             ^~~
/home/kaveman/.arduino15/packages/esp32/tools/esp32-arduino-libs/idf-release_v5.1-bd2b9390ef/esp32/include/http_parser/http_parser.h:139:3: note: in expansion of macro 'HTTP_METHOD_MAP'
  139 |   HTTP_METHOD_MAP(XX)
      |   ^~~~~~~~~~~~~~~
/home/kaveman/Arduino/libraries/ESPAsyncWebServer/src/ESPAsyncWebServer.h:67:3: note: previous declaration 'WebRequestMethod HTTP_HEAD'
   67 |   HTTP_HEAD    = 0b00100000,
      |   ^~~~~~~~~
/home/kaveman/.arduino15/packages/esp32/tools/esp32-arduino-libs/idf-release_v5.1-bd2b9390ef/esp32/include/http_parser/http_parser.h:98:6: error: 'HTTP_POST' conflicts with a previous declaration
   98 |   XX(3,  POST,        POST)         \
      |      ^
/home/kaveman/.arduino15/packages/esp32/tools/esp32-arduino-libs/idf-release_v5.1-bd2b9390ef/esp32/include/http_parser/http_parser.h:138:45: note: in definition of macro 'XX'
  138 | #define XX(num, name, string) HTTP_##name = num,
      |                                             ^~~
/home/kaveman/.arduino15/packages/esp32/tools/esp32-arduino-libs/idf-release_v5.1-bd2b9390ef/esp32/include/http_parser/http_parser.h:139:3: note: in expansion of macro 'HTTP_METHOD_MAP'
  139 |   HTTP_METHOD_MAP(XX)
      |   ^~~~~~~~~~~~~~~
/home/kaveman/Arduino/libraries/ESPAsyncWebServer/src/ESPAsyncWebServer.h:63:3: note: previous declaration 'WebRequestMethod HTTP_POST'
   63 |   HTTP_POST    = 0b00000010,
      |   ^~~~~~~~~
/home/kaveman/.arduino15/packages/esp32/tools/esp32-arduino-libs/idf-release_v5.1-bd2b9390ef/esp32/include/http_parser/http_parser.h:99:6: error: 'HTTP_PUT' conflicts with a previous declaration
   99 |   XX(4,  PUT,         PUT)          \
      |      ^
/home/kaveman/.arduino15/packages/esp32/tools/esp32-arduino-libs/idf-release_v5.1-bd2b9390ef/esp32/include/http_parser/http_parser.h:138:45: note: in definition of macro 'XX'
  138 | #define XX(num, name, string) HTTP_##name = num,
      |                                             ^~~
/home/kaveman/.arduino15/packages/esp32/tools/esp32-arduino-libs/idf-release_v5.1-bd2b9390ef/esp32/include/http_parser/http_parser.h:139:3: note: in expansion of macro 'HTTP_METHOD_MAP'
  139 |   HTTP_METHOD_MAP(XX)
      |   ^~~~~~~~~~~~~~~
/home/kaveman/Arduino/libraries/ESPAsyncWebServer/src/ESPAsyncWebServer.h:65:3: note: previous declaration 'WebRequestMethod HTTP_PUT'
   65 |   HTTP_PUT     = 0b00001000,
      |   ^~~~~~~~
/home/kaveman/.arduino15/packages/esp32/tools/esp32-arduino-libs/idf-release_v5.1-bd2b9390ef/esp32/include/http_parser/http_parser.h:102:6: error: 'HTTP_OPTIONS' conflicts with a previous declaration
  102 |   XX(6,  OPTIONS,     OPTIONS)      \
      |      ^
/home/kaveman/.arduino15/packages/esp32/tools/esp32-arduino-libs/idf-release_v5.1-bd2b9390ef/esp32/include/http_parser/http_parser.h:138:45: note: in definition of macro 'XX'
  138 | #define XX(num, name, string) HTTP_##name = num,
      |                                             ^~~
/home/kaveman/.arduino15/packages/esp32/tools/esp32-arduino-libs/idf-release_v5.1-bd2b9390ef/esp32/include/http_parser/http_parser.h:139:3: note: in expansion of macro 'HTTP_METHOD_MAP'
  139 |   HTTP_METHOD_MAP(XX)
      |   ^~~~~~~~~~~~~~~
/home/kaveman/Arduino/libraries/ESPAsyncWebServer/src/ESPAsyncWebServer.h:68:3: note: previous declaration 'WebRequestMethod HTTP_OPTIONS'
   68 |   HTTP_OPTIONS = 0b01000000,
      |   ^~~~~~~~~~~~
/home/kaveman/.arduino15/packages/esp32/tools/esp32-arduino-libs/idf-release_v5.1-bd2b9390ef/esp32/include/http_parser/http_parser.h:128:6: error: 'HTTP_PATCH' conflicts with a previous declaration
  128 |   XX(28, PATCH,       PATCH)        \
      |      ^~
/home/kaveman/.arduino15/packages/esp32/tools/esp32-arduino-libs/idf-release_v5.1-bd2b9390ef/esp32/include/http_parser/http_parser.h:138:45: note: in definition of macro 'XX'
  138 | #define XX(num, name, string) HTTP_##name = num,
      |                                             ^~~
/home/kaveman/.arduino15/packages/esp32/tools/esp32-arduino-libs/idf-release_v5.1-bd2b9390ef/esp32/include/http_parser/http_parser.h:139:3: note: in expansion of macro 'HTTP_METHOD_MAP'
  139 |   HTTP_METHOD_MAP(XX)
      |   ^~~~~~~~~~~~~~~
/home/kaveman/Arduino/libraries/ESPAsyncWebServer/src/ESPAsyncWebServer.h:66:3: note: previous declaration 'WebRequestMethod HTTP_PATCH'
   66 |   HTTP_PATCH   = 0b00010000,
      |   ^~~~~~~~~~
/home/kaveman/Arduino/libraries/EvilCrow-RF/EvilCrowRF-RAWv2/RAWv3.0-NewInterface/RAWv3.0-NewInterface.ino: In function 'void force_reset()':
/home/kaveman/Arduino/libraries/EvilCrow-RF/EvilCrowRF-RAWv2/RAWv3.0-NewInterface/RAWv3.0-NewInterface.ino:280:3: error: 'esp_task_wdt_add' was not declared in this scope
  280 |   esp_task_wdt_add(NULL);
      |   ^~~~~~~~~~~~~~~~
/home/kaveman/Arduino/libraries/EvilCrow-RF/EvilCrowRF-RAWv2/RAWv3.0-NewInterface/RAWv3.0-NewInterface.ino: In function 'void setup()':
/home/kaveman/Arduino/libraries/EvilCrow-RF/EvilCrowRF-RAWv2/RAWv3.0-NewInterface/RAWv3.0-NewInterface.ino:846:3: error: 'AsyncElegantOTA' was not declared in this scope; did you mean 'ElegantOTA'?
  846 |   AsyncElegantOTA.begin(&controlserver);
      |   ^~~~~~~~~~~~~~~
      |   ElegantOTA

exit status 1

Compilation error: 'esp_task_wdt_add' was not declared in this scope
`

kavemang, 2024-07-09:
wrong place

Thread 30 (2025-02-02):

SPIFFS depreciated

mattgp, 2025-02-02:
Hi,

The code won't compile in arduino IDE due to the above.

Is there a workaround, went to discord for support but the link has expired.

BR

Matt.

joelsernamoreno, 2025-02-14:
Hello

Yes, the ECRF V1 and V2 firmware are broken due to the latest library updates, I am programming the firmware from scratch again

Unfortunately this is the Evil Crow RF V1 firmware and has no alternative firmware, only Evil Crow RF V2

I will respond on this issue when I finish programming the firmware

Thanks

mattgp, 2025-02-15:
Hey,Thanks for the update and all the hard work.I actually worked around the issue by using an old library from another unrelated GitHub project, this created 2 minor compile errors which I just commented out.The result was firmware that worked well enough to log in and use OTA to install RAT firmware which I’ll use for the time being.The only nuance I noted was if I reboot the ECRF the firmware revered to my semi broken version ie non persistent uodste - weird.I fixed this by updating the rat firmware to itself using OTA a second time before rebooting again which fixed it.All the best,Matt.On 14 Feb 2025, at 23:52, Joel Serna Moreno ***@***.***> wrote:
  Hello
Yes, the ECRF V1 and V2 firmware are broken due to the latest library updates, I am programming the firmware from scratch again
Unfortunately this is the Evil Crow RF V1 firmware and has no alternative firmware, only Evil Crow RF V2
I will respond on this issue when I finish programming the firmware
Thanks—Reply to this email directly, view it on GitHub, or unsubscribe.You are receiving this because you authored the thread.Message ID: ***@***.***>

joelsernamoreno left a comment (joelsernamoreno/EvilCrow-RF#30)
Hello
Yes, the ECRF V1 and V2 firmware are broken due to the latest library updates, I am programming the firmware from scratch again
Unfortunately this is the Evil Crow RF V1 firmware and has no alternative firmware, only Evil Crow RF V2
I will respond on this issue when I finish programming the firmware
Thanks

—Reply to this email directly, view it on GitHub, or unsubscribe.You are receiving this because you authored the thread.Message ID: ***@***.***>

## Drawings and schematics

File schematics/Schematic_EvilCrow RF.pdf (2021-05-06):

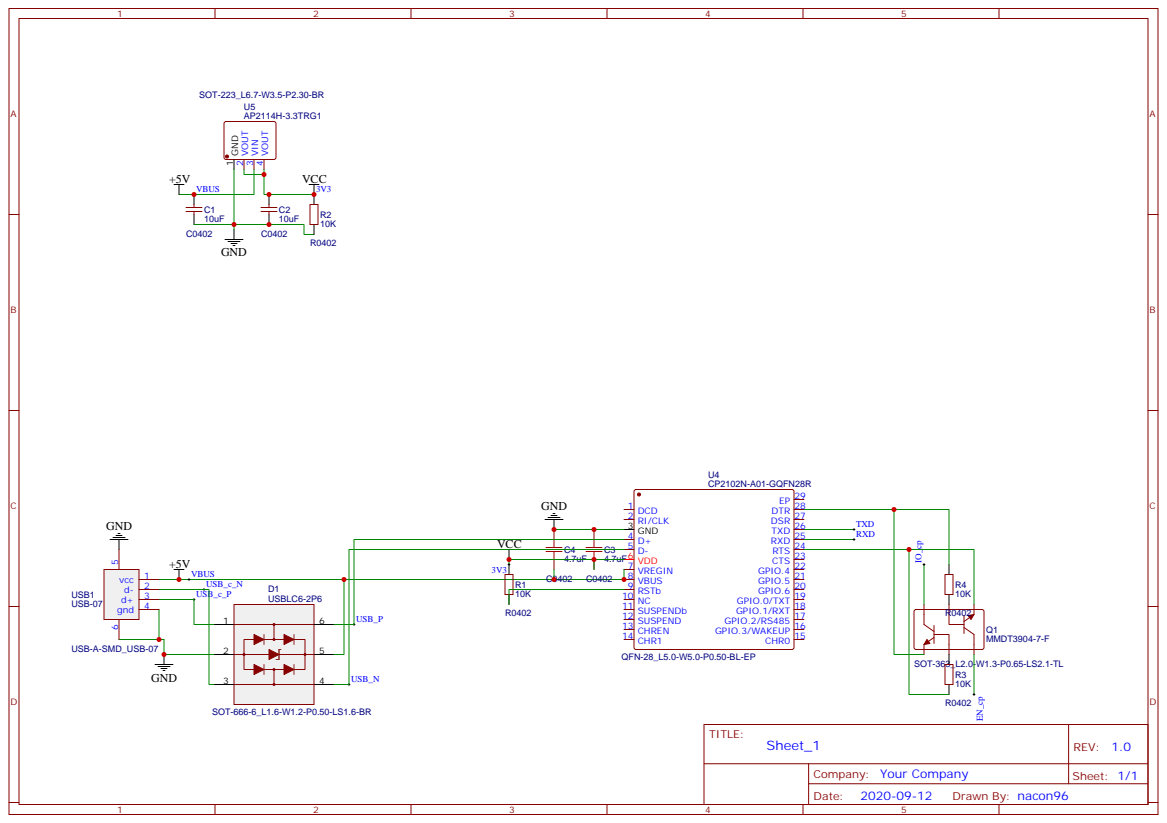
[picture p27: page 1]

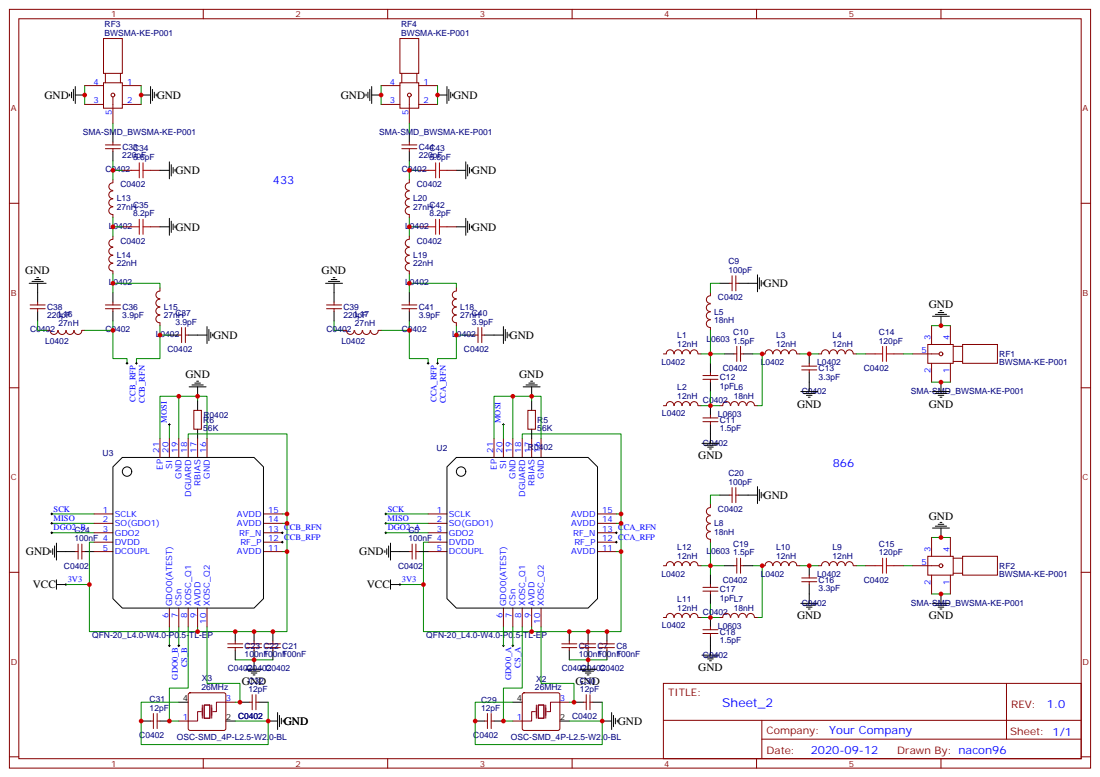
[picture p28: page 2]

GND 16 RBIAS 17 DGUARD 18 GND 19 SI 20 EP 21

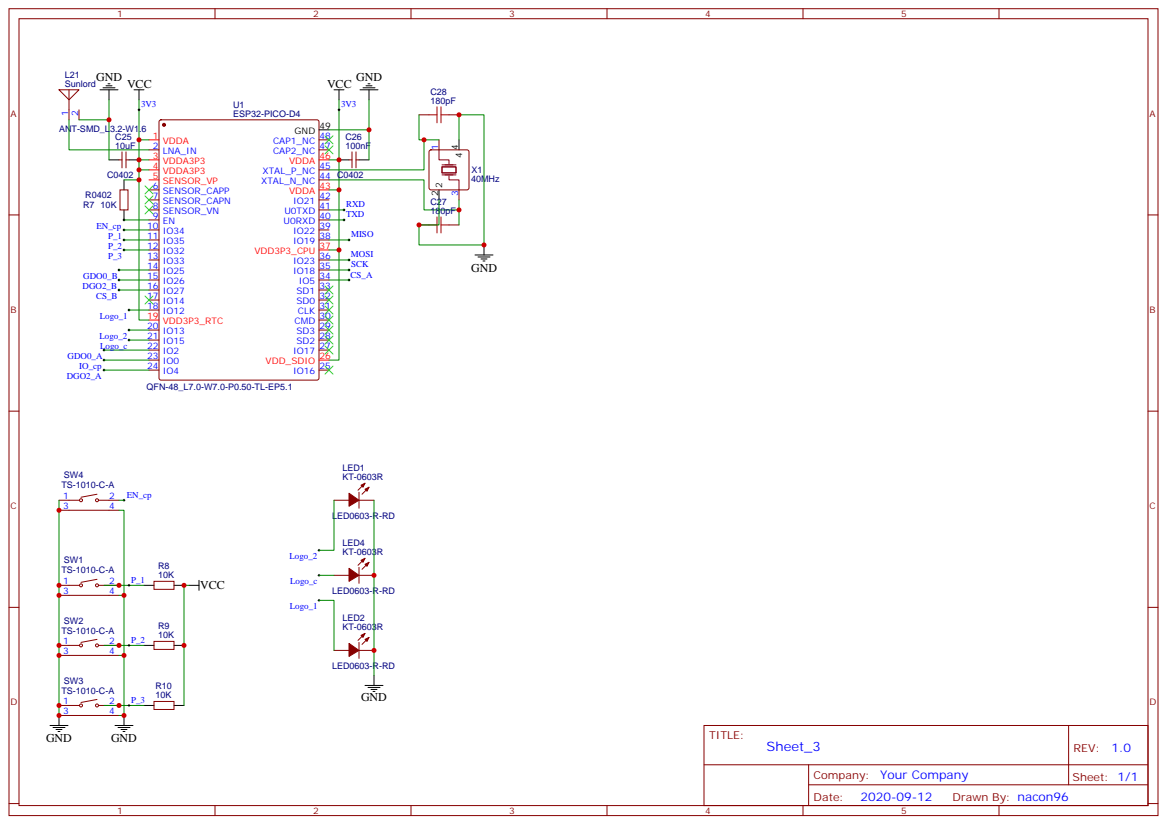
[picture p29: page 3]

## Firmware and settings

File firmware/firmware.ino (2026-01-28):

#include "ELECHOUSE_CC1101_SRC_DRV.h"
#include <SPI.h>
#include <ESPmDNS.h>
#include <WiFiClient.h> 
#include <WiFi.h>
#include <AsyncTCP.h>
#include <ESPAsyncWebServer.h>
#include <WiFiAP.h>
#include <LittleFS.h>
#include "rxconfig.h"
#include "txconfig.h"
#include "javascript.h"
#include "style.h"
#include "index.h"
#include "config.h"
#include "viewlog.h"

// Config SSID, password and channel
String defaultSSID = "Evil Crow RF";  // Enter your SSID here
String defaultPassword = "123456789ECRFv1";  //Enter your Password here
String hostname = "evilcrow-rf"; // Enter your hostname here

// SPI Pins
int sck_pin = 18;
int miso_pin = 19;
int mosi_pin = 23;

// CC1101 Module 1
int rx_pin1 = 4;
int tx_pin1 = 2;
int cs_pin1 = 5;

// CC1101 Module 2
int rx_pin2 = 26;
int tx_pin2 = 25;
int cs_pin2 = 27;

// RF variables
#define RECEIVE_ATTR IRAM_ATTR
#define samplesize 2000
int error_toleranz = 200;
const int minsample = 30;
unsigned long sample[samplesize];
unsigned long samplesmooth[samplesize];
String lastSampleSmooth;
int  lastIndex;
int samplecount;
static unsigned long lastTime = 0;
int mod;
float deviation;
int datarate;
float frequency;
float setrxbw;
int power_jammer;
byte jammer[] = { 0xff, 0xff };
const size_t jammer_len = sizeof(jammer) / sizeof(jammer[0]);
long data_to_send[2000];

// Other variables
const bool formatOnFail = true;
String OutputLog;

// File
File logs;

// Web Server
String tmp_module;
String tmp_frequency;
String tmp_setrxbw;
String tmp_mod;
String tmp_deviation;
String tmp_datarate;
String raw_rx = "0";
String jammer_tx = "0";
String transmit;
AsyncWebServer controlserver(80);

void connectToWiFi() {
  String wifiSSID = defaultSSID;
  String wifiPassword = defaultPassword;

  if (readWiFiConfig(wifiSSID, wifiPassword)) {
    Serial.println("Using saved Wi-Fi credentials.");
  } else {
    Serial.println("Using default Wi-Fi credentials.");
  }

  WiFi.mode(WIFI_STA);
  WiFi.begin(wifiSSID.c_str(), wifiPassword.c_str());

  Serial.print("Connecting to Wi-Fi: "); Serial.println(wifiSSID);
  unsigned long start = millis();

  while (WiFi.status() != WL_CONNECTED) {
    delay(500);
    Serial.print(".");
    if (millis() - start > 15000) { 
      Serial.println("\nFailed to connect to Wi-Fi.");
      break;
    }
  }

  if (WiFi.status() == WL_CONNECTED) {
    Serial.print("\nConnected! IP: "); Serial.println(WiFi.localIP());
  }
}

bool readWiFiConfig(String &ssid, String &password) {
  if (!LittleFS.exists("/wifi_config.txt")) {
    return false;
  }

  File file = LittleFS.open("/wifi_config.txt", "r");
  if (!file) {
    return false;
  }

  ssid = file.readStringUntil('\n');
  ssid.trim();

  password = file.readStringUntil('\n');
  password.trim();

  file.close();
  return ssid.length() && password.length();
}

void handleUpdateWiFi(AsyncWebServerRequest *request) {
  if (request->hasParam("ssid", true) && request->hasParam("password", true)) {
    String newSSID = request->getParam("ssid", true)->value();
    String newPassword = request->getParam("password", true)->value();

    if (LittleFS.exists("/wifi_config.txt")) {
      LittleFS.remove("/wifi_config.txt");
      //Serial.println("Existing Wi-Fi config file deleted.");
    }

    appendFile(LittleFS, "/wifi_config.txt", newSSID.c_str(), "\n");
    appendFile(LittleFS, "/wifi_config.txt", newPassword.c_str(), "\n");
    request->send(200, "application/json", "{\"status\":\"success\",\"message\":\"Wi-Fi config applied successfully! Device will restart.\"}");
    delay(500);
    ESP.restart();
  } else {
    request->send(400, "application/json", "{\"status\":\"error\",\"message\":\"Missing SSID or password\"}");
  }
}

void handleDeleteWiFiConfig(AsyncWebServerRequest *request) {
  if (LittleFS.exists("/wifi_config.txt")) {
    if (LittleFS.remove("/wifi_config.txt")) {
      request->send(200, "application/json", "{\"status\":\"success\",\"message\":\"Wi-Fi config deleted successfully\"}");
      ESP.restart();
    } else {
      request->send(500, "application/json", "{\"status\":\"error\",\"message\":\"Failed to delete the file\"}");
    }
  } else {
    request->send(404, "application/json", "{\"status\":\"error\",\"message\":\"Wi-Fi config file not found\"}");
  }
}

void handleStats(AsyncWebServerRequest *request) {
  size_t freeSpiffs = 0;
  
  if (LittleFS.begin(true)) {
    freeSpiffs = LittleFS.totalBytes() - LittleFS.usedBytes();
  }

  String json = "{";
  json += "\"uptime\":" + String(millis() / 1000);
  json += ",\"cpu0\":" + String(getCpuFrequencyMhz());
  json += ",\"cpu1\":" + String(getXtalFrequencyMhz());
  json += ",\"temperature\":" + String(temperatureRead());
  json += ",\"freespiffs\":" + String(freeSpiffs);
  json += ",\"totalram\":" + String(ESP.getHeapSize());
  json += ",\"freeram\":" + String(ESP.getFreeHeap());
  json += ",\"ssid\":\"" + WiFi.SSID() + "\"";
  json += ",\"ipaddress\":\"" + WiFi.localIP().toString() + "\"";
  json += "}";

  request->send(200, "application/json", json);
}

void appendFile(fs::FS &fs, const char * path, const char * message, String messagestring){
  logs = fs.open(path, FILE_APPEND);
  if(!logs){
    //Serial.println("Failed to open file for appending");
    return;
  }
  if(logs.print(message)|logs.print(messagestring)){
    //Serial.println("Message appended");
  } else {
    //Serial.println("Append failed");
  }
  logs.close();
}

void deleteFile(fs::FS &fs, const char * path){
  //Serial.printf("Deleting file: %s\n", path);
  if(fs.remove(path)){
    //Serial.println("File deleted");
  } else {
    //Serial.println("Delete failed");
  }
}

bool checkReceived(void) {
  delay(1);
  if (samplecount >= minsample && micros() - lastTime > 100000) {
    detachInterrupt(rx_pin1);
    detachInterrupt(rx_pin2);
    return true;
  } else {
    return false;
  }
}

void printReceived() {
  OutputLog = "";
  appendFile(LittleFS, "/logs.txt", "-------------------------------------------------------\n", "");
  //Serial.print("Count=");
  //Serial.println(samplecount);
  OutputLog += "\n";
  OutputLog += "Count=";
  OutputLog += String(samplecount);
  OutputLog += "\n";

  for (int i = 0; i < samplecount; i++) {
    //Serial.print(sample[i]);
    //Serial.print(",");
    OutputLog += String(sample[i]);
    OutputLog += ",";
  }
  //Serial.println();
  //Serial.println();
  OutputLog += "\n";
  appendFile(LittleFS, "/logs.txt", NULL, OutputLog.c_str());
}

void RECEIVE_ATTR receiver() {
  const long time = micros();
  const unsigned int duration = time - lastTime;

  if (duration > 100000) {
    samplecount = 0;
  }

  if (duration >= 100 && samplecount < samplesize) {
    sample[samplecount++] = duration;
  }

  /*if (duration >= 100) {
    sample[samplecount++] = duration;
  }*/

  if (samplecount >= samplesize) {
    samplecount = samplesize - 1;
    bool received = checkReceived();
    if (received) {}
    detachInterrupt(rx_pin1);
    detachInterrupt(rx_pin2);
  }

  if (mod == 0) {
    if (samplecount == 1 and digitalRead(rx_pin2) != HIGH){
      samplecount = 0;
    }

    else if (samplecount == 1 and digitalRead(rx_pin1) != HIGH){
      samplecount = 0;
    }
  }

  lastTime = time;
}

void signalanalyse(){
  OutputLog = "";
  #define signalstorage 10

  int signalanz=0;
  int timingdelay[signalstorage];
  //float pulse[signalstorage];
  long signaltimings[signalstorage*2];
  int signaltimingscount[signalstorage];
  long signaltimingssum[signalstorage];
  long signalsum=0;
  
  for (int i = 0; i<signalstorage; i++){
    signaltimings[i*2] = 100000;
    signaltimings[i*2+1] = 0;
    signaltimingscount[i] = 0;
    signaltimingssum[i] = 0;
  }
  for (int i = 1; i<samplecount; i++){
    signalsum+=sample[i];
  }

  for (int p = 0; p<signalstorage; p++){

  for (int i = 1; i<samplecount; i++){
    if (p==0){
      if (sample[i]<signaltimings[p*2]){
        signaltimings[p*2]=sample[i];
      }
    }else{
      if (sample[i]<signaltimings[p*2] && sample[i]>signaltimings[p*2-1]){
        signaltimings[p*2]=sample[i];
      }
    }
  }

  for (int i = 1; i<samplecount; i++){
    if (sample[i]<signaltimings[p*2]+error_toleranz && sample[i]>signaltimings[p*2+1]){
      signaltimings[p*2+1]=sample[i];
    }
  }

  for (int i = 1; i<samplecount; i++){
    if (sample[i]>=signaltimings[p*2] && sample[i]<=signaltimings[p*2+1]){
      signaltimingscount[p]++;
      signaltimingssum[p]+=sample[i];
    }
  }
  }
  int firstsample = signaltimings[0];
  signalanz=signalstorage;

  for (int i = 0; i<signalstorage; i++){
    if (signaltimingscount[i] == 0){
      signalanz=i;
      i=signalstorage;
    }
  }

  for (int s=1; s<signalanz; s++){
  for (int i=0; i<signalanz-s; i++){
    if (signaltimingscount[i] < signaltimingscount[i+1]){
      int temp1 = signaltimings[i*2];
      int temp2 = signaltimings[i*2+1];
      int temp3 = signaltimingssum[i];
      int temp4 = signaltimingscount[i];
      signaltimings[i*2] = signaltimings[(i+1)*2];
      signaltimings[i*2+1] = signaltimings[(i+1)*2+1];
      signaltimingssum[i] = signaltimingssum[i+1];
      signaltimingscount[i] = signaltimingscount[i+1];
      signaltimings[(i+1)*2] = temp1;
      signaltimings[(i+1)*2+1] = temp2;
      signaltimingssum[i+1] = temp3;
      signaltimingscount[i+1] = temp4;
    }
  }
  }

  for (int i=0; i<signalanz; i++){
    timingdelay[i] = signaltimingssum[i]/signaltimingscount[i];
  }

  if (firstsample == sample[1] and firstsample < timingdelay[0]){
    sample[1] = timingdelay[0];
  }

  bool lastbin=0;
  for (int i=1; i<samplecount; i++){
    float r = (float)sample[i]/timingdelay[0];
    int calculate = r;
    r = r-calculate;
    r*=10;
    if (r>=5){calculate+=1;}
    if (calculate>0){
      if (lastbin==0){
        lastbin=1;
      }else{
      lastbin=0;
    }
      if (lastbin==0 && calculate>8){
        //Serial.print(" [Pause: ");
        //Serial.print(sample[i]);
        //Serial.println(" samples]");
        OutputLog += " [Pause: ";
        OutputLog += String(sample[i]);
        OutputLog += " samples]\n";

      } else{
        for (int b=0; b<calculate; b++){
          //Serial.print(lastbin);
          OutputLog += String(lastbin);
        }
      }
    }
  }
  //Serial.println();
  //Serial.print("Samples/Symbol: ");
  //Serial.println(timingdelay[0]);
  //Serial.println();
  OutputLog += "\nSamples/Symbol: ";
  OutputLog += String(timingdelay[0]);
  OutputLog += "\n\n";

  int smoothcount=0;

  for (int i=1; i<samplecount; i++){
    float r = (float)sample[i]/timingdelay[0];
    int calculate = r;
    r = r-calculate;
    r*=10;
    if (r>=5){calculate+=1;}
    if (calculate>0){
      samplesmooth[smoothcount] = calculate*timingdelay[0];
      smoothcount++;
    }
  }
  appendFile(LittleFS, "/logs.txt", NULL, "\n");
  //Serial.println("Rawdata corrected:");
  //Serial.print("Count=");
  //Serial.println(smoothcount+1);
  lastIndex = smoothcount - 1;
  lastSampleSmooth = samplesmooth[lastIndex];

  OutputLog += "Rawdata corrected:\n";
  OutputLog += "Count=";
  OutputLog += String(smoothcount + 1);
  OutputLog += "\n";

  for (int i=0; i<smoothcount; i++){
    //Serial.print(samplesmooth[i]);
    //Serial.print(",");
    OutputLog += String(samplesmooth[i]);
    OutputLog += ",";
  }
  //Serial.println();
  //Serial.println();
  appendFile(LittleFS, "/logs.txt", NULL, OutputLog.c_str());
  appendFile(LittleFS, "/logs.txt", NULL, "\n");
  appendFile(LittleFS, "/logs.txt", "-------------------------------------------------------\n", "");
  return;
}

void enableReceive() {
  rx_pin1 = digitalPinToInterrupt(rx_pin1);
  rx_pin2 = digitalPinToInterrupt(rx_pin2);
  pinMode(rx_pin1, INPUT);
  pinMode(rx_pin2, INPUT);
  ELECHOUSE_cc1101.SetRx();
  samplecount = 0;
  attachInterrupt(rx_pin1, receiver, CHANGE);
  attachInterrupt(rx_pin2, receiver, CHANGE);
}

void setup() {

  Serial.begin(38400);

  if (!LittleFS.begin(true)) {
    LittleFS.format();
    delay(1000);
    ESP.restart();
  }

  delay(2000);
  connectToWiFi();

  if (!MDNS.begin(hostname.c_str())) {
    //Serial.println("Error setting up MDNS responder!");
  }


  controlserver.on("/", HTTP_GET, [](AsyncWebServerRequest *request) {
    request->send(200, "text/html", Index);
  });

  controlserver.on("/rxconfig", HTTP_GET, [](AsyncWebServerRequest *request) {
    request->send(200, "text/html", RXConfig);
  });

  controlserver.on("/viewlog", HTTP_GET, [](AsyncWebServerRequest *request){
    request->send(200, "text/html", ViewLog);
  });

  controlserver.on("/logs", HTTP_GET, [](AsyncWebServerRequest *request){
    request->send(LittleFS, "/logs.txt", "text/plain");
  });

  controlserver.on("/txconfig", HTTP_GET, [](AsyncWebServerRequest *request) {
    request->send(200, "text/html", TXConfig);
  });

  controlserver.on("/delete", HTTP_POST, [](AsyncWebServerRequest *request){
    deleteFile(LittleFS, "/logs.txt");
    request->send(200, "application/json", "{\"status\":\"deleted\"}");
  });

  controlserver.on("/config", HTTP_GET, [](AsyncWebServerRequest *request) {
    request->send(200, "text/html", Config);
  });

  controlserver.on("/updatewifi", HTTP_POST, handleUpdateWiFi);
  controlserver.on("/deletewificonfig", HTTP_POST, handleDeleteWiFiConfig);
  controlserver.on("/stats", HTTP_GET, handleStats);

  controlserver.on("/reboot", HTTP_POST, [](AsyncWebServerRequest *request){
    request->send(200, "application/json", "{\"success\":true,\"message\":\"Device rebooting\"}");
    delay(200);
    ESP.restart();
  });

  controlserver.on("/connectioncheck", HTTP_GET, [](AsyncWebServerRequest *request) {
    request->send(200, "application/json", "{\"status\":\"ok\"}");
  });

  controlserver.on("/javascript.js", HTTP_GET, [](AsyncWebServerRequest *request) {
    request->send(200, "text/javascript", JavaScript);
  });

  controlserver.on("/setrx", HTTP_POST, [](AsyncWebServerRequest *request) {
    if (!request->hasArg("module") || !request->hasArg("frequency") ||
      !request->hasArg("setrxbw") || !request->hasArg("mod") ||
      !request->hasArg("deviation") || !request->hasArg("datarate")) {

      request->send(400, "application/json", "{\"status\":\"error\",\"message\":\"Missing parameters\"}");
      return;
    }

    tmp_module = request->arg("module");
    tmp_frequency = request->arg("frequency");
    tmp_setrxbw = request->arg("setrxbw");
    tmp_mod = request->arg("mod");
    tmp_deviation = request->arg("deviation");
    tmp_datarate = request->arg("datarate");

    if (request->hasArg("configmodule")) {
      frequency = tmp_frequency.toFloat();
      setrxbw = tmp_setrxbw.toFloat();
      mod = tmp_mod.toInt();
      deviation = tmp_deviation.toFloat();
      datarate = tmp_datarate.toInt();

      if (tmp_module == "1") {
        ELECHOUSE_cc1101.setModul(0);
        ELECHOUSE_cc1101.Init();
      } else if (tmp_module == "2") {
        ELECHOUSE_cc1101.setModul(1);
        ELECHOUSE_cc1101.Init();
      }

      if (mod == 2) {
        ELECHOUSE_cc1101.setDcFilterOff(0);
      } else if (mod == 0) {
        ELECHOUSE_cc1101.setDcFilterOff(1);
        ELECHOUSE_cc1101.setDeviation(deviation);
      }

      ELECHOUSE_cc1101.setModulation(mod);
      ELECHOUSE_cc1101.setMHZ(frequency);
      ELECHOUSE_cc1101.setSyncMode(0);
      ELECHOUSE_cc1101.setPktFormat(3);
      ELECHOUSE_cc1101.setRxBW(setrxbw);
      ELECHOUSE_cc1101.setDRate(datarate);
      enableReceive();
      raw_rx = "1";
      request->send(200, "application/json", "{\"status\":\"success\",\"message\":\"RX configuration applied successfully.\"}");
    } else {
      request->send(400, "application/json", "{\"status\":\"error\",\"message\":\"Missing configmodule parameter\"}");
    }
  });

  controlserver.on("/stoprx", HTTP_POST, [](AsyncWebServerRequest *request) {
    ELECHOUSE_cc1101.setModul(0);
    ELECHOUSE_cc1101.setSidle();
    ELECHOUSE_cc1101.setModul(1);
    ELECHOUSE_cc1101.setSidle();

    raw_rx = "0";
    request->send(200, "application/json", "{\"status\":\"success\",\"message\":\"RX stopped.\"}");
  });

  controlserver.on("/settx", HTTP_POST, [](AsyncWebServerRequest *request){
    if (!request->hasArg("module") || !request->hasArg("frequency") || 
      !request->hasArg("rawdata") || !request->hasArg("mod") || !request->hasArg("deviation")) {
      request->send(400, "text/plain", "Missing parameters");
      return;
    }

    tmp_module = request->arg("module");
    tmp_frequency = request->arg("frequency");
    transmit = request->arg("rawdata");
    tmp_deviation = request->arg("deviation");
    tmp_mod = request->arg("mod");

    int counter = 0;
    int pos = 0;
    frequency = tmp_frequency.toFloat();
    deviation = tmp_deviation.toFloat();
    mod = tmp_mod.toInt();

    for (int i = 0; i < transmit.length(); i++){
      if (transmit.substring(i, i+1) == ",") {
        data_to_send[counter++] = transmit.substring(pos, i).toInt();
        pos = i+1;
      }
    }
    if (pos < transmit.length()) data_to_send[counter++] = transmit.substring(pos).toInt();

    int tx_pin = (tmp_module == "1") ? 2 : 25;
    ELECHOUSE_cc1101.setModul((tmp_module == "1") ? 0 : 1);
    ELECHOUSE_cc1101.Init();
    ELECHOUSE_cc1101.setModulation(mod);
    ELECHOUSE_cc1101.setMHZ(frequency);
    ELECHOUSE_cc1101.setDeviation(deviation);
    ELECHOUSE_cc1101.SetTx();
    pinMode(tx_pin, OUTPUT);

    for (int i = 0; i < counter; i += 2) {
      digitalWrite(tx_pin, HIGH);
      delayMicroseconds(data_to_send[i]);
      digitalWrite(tx_pin, LOW);
      delayMicroseconds(data_to_send[i+1]);
      //Serial.print(data_to_send[i]);
      //Serial.print(",");
    }

    ELECHOUSE_cc1101.setSidle();
    request->send(200, "text/plain", "Signal has been transmitted");
});


  controlserver.on("/setjammer", HTTP_POST, [](AsyncWebServerRequest *request){
    if (!request->hasArg("module") || !request->hasArg("frequency") || !request->hasArg("power")) {
      request->send(400, "application/json", "{\"status\":\"error\",\"message\":\"Missing parameters (module, frequency, power required)\"}");
      return;
    }

    tmp_module = request->arg("module");
    frequency = request->arg("frequency").toFloat();
    int power_jammer = request->arg("power").toInt();

    if (tmp_module != "1" && tmp_module != "2") {
      request->send(400, "application/json", "{\"status\":\"error\",\"message\":\"Invalid module (must be 1 or 2)\"}");
      return;
    }

    int moduleIndex = (tmp_module == "1") ? 0 : 1;
    int tx_pin = (tmp_module == "1") ? tx_pin1 : tx_pin2;

    pinMode(tx_pin, OUTPUT);
    ELECHOUSE_cc1101.setModul(moduleIndex);
    ELECHOUSE_cc1101.Init();
    ELECHOUSE_cc1101.setModulation(2);
    ELECHOUSE_cc1101.setMHZ(frequency);
    ELECHOUSE_cc1101.setPA(power_jammer);
    ELECHOUSE_cc1101.SetTx();

    jammer_tx = "1";
    request->send(200, "application/json", "{\"status\":\"success\",\"message\":\"Jammer started\"}");
  });

  controlserver.on("/stopjammer", HTTP_POST, [](AsyncWebServerRequest *request) {
    ELECHOUSE_cc1101.setModul(0);
    ELECHOUSE_cc1101.setSidle();
    ELECHOUSE_cc1101.setModul(1);
    ELECHOUSE_cc1101.setSidle();

    jammer_tx = "0";
    request->send(200, "application/json", "{\"status\":\"success\",\"message\":\"Jammer stopped\"}");
  });

  controlserver.on("/style.css", HTTP_GET, [](AsyncWebServerRequest *request) {
    request->send(200, "text/css", Style);
  });

  controlserver.begin();
  ELECHOUSE_cc1101.addSpiPin(sck_pin, miso_pin, mosi_pin, cs_pin1, 0);
  ELECHOUSE_cc1101.addSpiPin(sck_pin, miso_pin, mosi_pin, cs_pin2, 1);

  enableReceive();
}

void loop() {
  if(raw_rx == "1") {
    if(checkReceived()){
      printReceived();
      signalanalyse();
      enableReceive();
      delay(700);
    }
  }
  if(jammer_tx == "1") {
    if (tmp_module == "1") {
      for (int i = 0; i + 1 < jammer_len; i += 2){
        digitalWrite(tx_pin1,HIGH);
        delayMicroseconds(jammer[i]);
        digitalWrite(tx_pin1,LOW);
        delayMicroseconds(jammer[i+1]);
      }
    }
    else if (tmp_module == "2") {
      for (int i = 0; i + 1 < jammer_len; i += 2){
        digitalWrite(tx_pin2,HIGH);
        delayMicroseconds(jammer[i]);
        digitalWrite(tx_pin2,LOW);
        delayMicroseconds(jammer[i+1]);
      }
    }
  }
}

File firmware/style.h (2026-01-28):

const char Style[] PROGMEM = R"=====(
:root {
  --primary: #00f2ff;
  --secondary: #00ff88;
  --accent: #ff00aa;
  --dark: #0a0a12;
  --darker: #050508;
  --light: #f0f0ff; /* Changed from #e0e0ff */
  --success: #00ff88;
  --error: #ff0033;
  --warning: #ffaa00;
}

body {
  background-color: #000000; /* Pure black */
  color: var(--light);
  font-family: 'Courier New', monospace;
  margin: 0;
  padding: 0;
  overflow-x: hidden;
  line-height: 1.6;
}

/* Header/Navigation - Mobile First */
#menu {
  background: var(--darker);
  border-bottom: 1px solid var(--primary);
  box-shadow: 0 0 15px rgba(0, 242, 255, 0.3);
  padding: 10px 0;
  position: relative; /* Changed from sticky to relative */
  top: auto; /* Remove sticky positioning */
  z-index: 100;
}

#menu ul {
  display: none;
  flex-direction: column;
  padding: 0;
  margin: 0;
  list-style: none;
  width: 100%;
}

#menu li {
  margin: 5px 0;
  position: relative;
}

#menu a {
  color: var(--light);
  text-decoration: none;
  padding: 10px 15px;
  display: block;
  transition: all 0.3s;
  position: relative;
  -webkit-tap-highlight-color: transparent;
  touch-action: manipulation; /* Disable double-tap zoom */
}

#menu a:hover {
  color: var(--primary);
  background: rgba(0, 242, 255, 0.1);
  will-change: width; 
}

#menu a::after {
  content: '';
  position: absolute;
  bottom: 0;
  left: 50%;
  transform: translateX(-50%);
  width: 0;
  height: 2px;
  background: var(--primary);
  transition: width 0.3s;
}

#menu a:hover::after {
  width: 70%;
}

#menu .usb-icon {
  vertical-align: middle;
  margin-right: 5px;
}

/* Active menu item */
#menu a.active {
  color: var(--primary);
  font-weight: bold;
}

#menu a.active::after {
  width: 70%;
}

/* Hamburger menu - Mobile - Left side */
#responsive-menu + label {
  display: block;
  cursor: pointer;
  padding: 5px 15px;
  position: absolute;
  top: 0;
  left: 0;
  z-index: 101;
  background: var(--darker); /* Add background to match menu */
}

#responsive-menu + label::before {
  content: "☰";
  font-size: 1.5em;
  color: var(--primary);
}

#responsive-menu:checked + label::before {
  content: "✕";
}

#responsive-menu:checked ~ ul {
  display: flex;
  flex-direction: column;
  align-items: center; /* Center menu items */
  text-align: center; /* Center text */
  padding-top: 60px; /* Make space for hamburger */
}

/* Adjust menu items for centered layout */
#responsive-menu:checked ~ ul li {
  width: 100%;
  text-align: center;
}

#responsive-menu:checked ~ ul a {
  justify-content: center;
}

/* Main content */
.view-container {
  -webkit-transform: translate3d(0,0,0);
  transform: translateZ(0);
  will-change: transform;
  background: rgba(10, 10, 18, 0.8);
  border: 1px solid var(--primary);
  border-radius: 5px;
  padding: 15px;
  margin-top: 20px;
  margin: 15px auto;
  max-width: 900px;
  box-shadow: 0 0 20px rgba(0, 242, 255, 0.1);
  position: relative;
  overflow: hidden;
  min-height: 350px;
}

.view-container::before {
  content: "";
  position: absolute;
  top: 0;
  left: 0;
  width: 100%;
  height: 3px;
  background: linear-gradient(90deg, var(--primary), var(--secondary));
}

/* Buttons */
button, input[type="submit"], input[type="button"] {
  background: linear-gradient(135deg, var(--primary), var(--secondary));
  color: var(--darker);
  border: none;
  padding: 5px 5px;
  font-weight: bold;
  border-radius: 3px;
  cursor: pointer;
  transition: all 0.3s;
  text-transform: uppercase;
  letter-spacing: 1px;
  position: relative;
  overflow: hidden;
  font-family: 'Courier New', monospace;
  font-size: 12px;
  margin: 5px;
  min-height: 44px;
}

button:hover, input[type="submit"]:hover, input[type="button"]:hover {
  transform: translateY(-2px);
  box-shadow: 0 5px 15px rgba(0, 242, 255, 0.4);
}

button::after {
  content: "";
  position: absolute;
  top: 0;
  left: -100%;
  width: 100%;
  height: 100%;
  background: linear-gradient(90deg, transparent, rgba(255, 255, 255, 0.2), transparent);
  transition: 0.5s;
}

button:hover::after {
  left: 100%;
}

button[name="deleteWifiButton"], 
button[name="deleteUSBButton"],
button[name="deleteBackupWifiButton"],
button[name="clearCacheButton"] {
  background: linear-gradient(135deg, var(--error), #cc0022);
}

button[name="deleteAllPayloads"] {
    background: linear-gradient(135deg, var(--error), #cc0022);
    min-width: auto;
    margin: 0;
    width: auto;
    flex-shrink: 0;
    white-space: nowrap; /* Prevent text wrapping */
}

/* Input fields - Improved for mobile */
/* Form inputs - one line height */
input:not([type="checkbox"]):not([type="file"]),
select {
  height: 36px; /* Fixed height for single-line inputs */
  padding: 8px 12px;
  line-height: 1.2;
}

textarea {
  min-height: 100px; /* Keep textareas taller */
  resize: none;
}

* {
  -webkit-tap-highlight-color: transparent;
}

.single-line-input {
  height: 36px !important;
  line-height: 36px !important;
  padding: 0 12px !important;
}

input, textarea, select {
  background: rgba(0, 0, 0, 0.3);
  border: 1px solid var(--primary);
  color: var(--light);
  padding: 8px 12px;
  border-radius: 3px;
  width: 100%;
  margin-bottom: 12px;
  font-family: 'Courier New', monospace;
  transition: all 0.3s;
  box-sizing: border-box;
  font-size: 16px !important;
}

input:focus, textarea:focus, select:focus {
  outline: none;
  border-color: var(--secondary);
  box-shadow: 0 0 10px rgba(0, 255, 136, 0.3);
}*/

input[type="checkbox"] {
  width: auto;
  margin-right: 10px;
}

/* Form groups - Improved spacing */
.form-group {
  margin-bottom: 15px;
}

.form-group label {
  display: block;
  margin-top: 10px;
  margin-bottom: 6px;
  color: var(--primary);
  font-weight: bold;
  font-size: 1em;
}

/* Validation styles */
#validationStatus {
  display: block;
  font-size: 0.85em;
  white-space: pre-wrap;
  font-family: 'Courier New', monospace;
  background-color: rgba(10, 10, 10, 0.9);
  padding: 8px;
  border-radius: 3px;
  border-left: 3px solid var(--error);
  margin-top: 5px;
}

.validation-ok {
  color: var(--success);
  border-left-color: var(--success) !important;
}

.validation-error {
  color: var(--error);
}

.validation-empty {
    color: #666; /* Gray color for empty state */
    font-style: italic;
    display: block; /* Ensure it's visible */
}

/* Desktop specific styles */
@media (min-width: 768px) {
  #validationStatus {
    padding-left: 30px;
    text-indent: -20px;
    line-height: 1.4;
  }
  
  #validationStatus::before {
    content: "→ ";
    color: var(--primary);
    margin-right: 5px;
  }
}

/* Mobile specific styles */
@media (max-width: 767px) {
  #validationStatus {
    padding-left: 15px;
  }
}

/* Payload list */
.payload-list-container {
  display: grid;
  grid-template-columns: repeat(auto-fill, minmax(280px, 1fr));
  gap: 12px;
  margin: 15px 0;
}

.payload-item {
    border: 1px solid var(--primary);
    border-radius: 3px;
    padding: 12px;
    margin-bottom: 12px;
    background-color: rgba(10, 10, 10, 0.9);
}
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

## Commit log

2021-04-20 Adding 3D Case
    [EvilCrowRF_Case.stl, EvilCrowRF_Cover.stl]
2022-01-10 Screwless housing for Evil Crow Rf V1
    [ECRF_1_2_3_BUTTON.stl, ECRF_BOTTOM.stl, ECRF_CAP.stl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]
2022-04-05 New case added
    Newly redesigned V1 case added for better printability.
    [ECRF_1_2_3_BUTTON.stl, ECRF_BOTTOM.stl, ECRF_CAP.stl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]
